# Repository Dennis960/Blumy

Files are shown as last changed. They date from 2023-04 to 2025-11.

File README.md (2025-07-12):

# Blumy

- A smart soil moisture sensor

## Project Structure

- [.devcontainer](.devcontainer): Contains the configurations for the devcontainers
- [.github](.github): Contains the configuration for GitHub Actions
- [Board](Board): Contains the KiCad project for the board
- [Panel](Panel): Contains the KiCad project for the board panel. Generation of the panel is done with `KiKit`
- [Firmware](Firmware): Contains the firmware for the esp(32) sensor (uses esp-idf)
- [Pages](Pages): Contains the website for the project's showcase
- [Server](Server): Contains the website for displaying sensor data

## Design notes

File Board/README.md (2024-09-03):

# This project uses KiCad 7

## Plugins:

- [Fabrication ToolKit](https://github.com/bennymeg/JLC-Plugin-for-KiCad)

## Other software

- [JLC2KiCadLib Downloader](https://github.com/TousstNicolas/JLC2KiCad_lib)
- inside Board run `JLC2KiCadLib C94599 C1525 C1525 C1527 C16780 C15195 C15525 C2297 C81598 C84256 C26082 C25905 C11702 C25744 C4109 C318884 C318884 C2827328 C146233 C6186 C778186 C5736265 C10418 C2997435 -dir lib -model_dir packages3d -footprint_lib CustomFootprints.pretty -symbol_lib_dir symbol -symbol_lib Custom_Parts`

## PCB Manufacturer

- [JLCPCB](https://jlcpcb.com/)

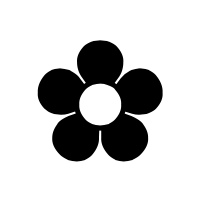
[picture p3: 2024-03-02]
Board/imgs/Flower.png

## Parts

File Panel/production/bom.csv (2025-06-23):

Designator | Footprint | Quantity | Value | LCSC Part #
BZ1_2, BZ1 | BUZ-SMD_4P-L8.5-W8.5-P8.50-BR | 2 | Buzzer | C94599
C1_2, C1, C10_2, C10, C12_2, C12, C6_2, C6, C7_2, C7, C9_2, C9 | 0402 | 12 | 10uF | C15525
C11_2, C11, C5_2, C5 | 0402 | 4 | 100nF-Ceramic | C1525
C2_2, C2 | 0402 | 2 | 10pF | C32949
C3_2, C3, C8_2, C8 | 0402 | 4 | 10nF | C15195
D1_2, D1 | LED0805-R-RD | 2 | GREEN | C2297
D2_2, D2 | SOD-123F_L2.7-W1.6-LS3.8-RD | 2 | Switching-Diode | C81598
D3_2, D3 | LED0805-R-RD | 2 | RED | C84256
L1_2, L1 | L0806 | 2 | 1.5uH | C668311
R1_2, R1 | 0402 | 2 | 287k | C321426
R10_2, R10, R11_2, R11, R12_2, R12, R2_2, R2, R4_2, R4 | 0402 | 10 | 5k1 | C25905
R13_2, R13, R14_2, R14 | 0402 | 4 | 120 | C25079
R15_2, R15 | 0402 | 2 | 51.1k | C284602
R3_2, R3 | 0402 | 2 | 100k | C25741
R5_2, R5, R8_2, R8, R9_2, R9 | 0402 | 6 | 10k | C25744
R6_2, R6 | 0402 | 2 | 2k | C4109
REF1_2, REF1 | DSBGA-8_L1.8-W1.1-R2-C4-P0.40-BR | 2 | TPS63036YFGR | C283955
U1_2, U1 | USB-C-SMD_G-SWITCH_GT-USB-7010EN | 2 | USB-C | C2997435
U13_2, U13 | WIFIM-SMD_61P-L16.6-W13.2-P0.80-ESP32-C6-MINI-1-N4 | 2 | ESP32-C6-MINI-1-N4 | C5736265
U3_2, U3 | SENSOR-SMD-6_AHT20 | 2 | AHT20 | C2757850
U4_2, U4, U7_2, U7 | SW-SMD_L3.9-W3.0-P4.45 | 4 | Tactile-Switch | C720477
U6_2, U6 | SENSORS-SMD_ALS-PT19 | 2 | Light sensor | C146233
U8_2, U8 | SW-SMD_MK-12C02-G025 | 2 | Slide-Switch | C778186

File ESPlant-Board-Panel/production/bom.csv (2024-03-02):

Designator | Footprint | Quantity | Value | LCSC Part #
BZ1_2, BZ1 | BUZ-SMD_4P-L8.5-W8.5-P8.50-BR | 2 | Buzzer | C94599
C1_2, C1 | 0402 | 2 | 2.2uF-Ceramic | C23630
C10_2, C10 | CAP-SMD_L3.2-W1.6-RD-C7171 | 2 | 10uF-Tantalum | C7171
C11_2, C11, C5_2, C5, C6_2, C6 | 0402 | 6 | 100nF-Ceramic | C1525
C2_2, C2 | CASE-B_3528 | 2 | 100uF-Tantalum | C16133
C3_2, C3, C8_2, C8 | 0402 | 4 | 10nF | C15195
C7_2, C7, C9_2, C9 | 0402 | 4 | 10uF | C15525
D1_2, D1 | LED0805-R-RD | 2 | GREEN | C2297
D2_2, D2 | SOD-123F_L2.7-W1.6-LS3.8-RD | 2 | Switching-Diode | C81598
D3_2, D3 | LED0805-R-RD | 2 | RED | C84256
L1_2, L1 | IND-SMD_L3.5-W3.0 | 2 | 6.8uH | C492260
R1_2, R1 | 0402 | 2 | 100k | C25741
R10_2, R10, R11_2, R11, R12_2, R12, R2_2, R2, R4_2, R4 | 0402 | 10 | 5k1 | C25905
R13_2, R13, R14_2, R14 | 0402 | 4 | 120 | C25079
R15_2, R15 | 0402 | 2 | 1M | C26083
R16_2, R16 | 0402 | 2 | 200k | C25764
R17_2, R17 | 0402 | 2 | 20k | C25765
R3_2, R3 | 0402 | 2 | 47k | C25792
R5_2, R5, R7_2, R7, R8_2, R8, R9_2, R9 | 0402 | 8 | 10k | C25744
R6_2, R6 | 0402 | 2 | 2k | C4109
U1_2, U1 | USB-C-SMD_G-SWITCH_GT-USB-7010EN | 2 | USB-C | C2997435
U13_2, U13 | WIFIM-SMD_61P-L16.6-W13.2-P0.80-ESP32-C6-MINI-1-N4 | 2 | ESP32-C6-MINI-1-N4 | C5736265
U3_2, U3 | SENSOR-SMD-6_AHT20 | 2 | AHT20 | C2757850
U4_2, U4, U7_2, U7 | SW-SMD_L3.9-W3.0-P4.45 | 4 | Tactile-Switch | C720477
U5_2, U5 | VSON-10_L3.0-W3.0-P0.50-BL-EP_TPS62410DRCR | 2 | 3.3V-Regulator | C71369
U6_2, U6 | SENSORS-SMD_ALS-PT19 | 2 | Light sensor | C146233
U8_2, U8 | SW-SMD_MK-12C02-G025 | 2 | Slide-Switch | C778186

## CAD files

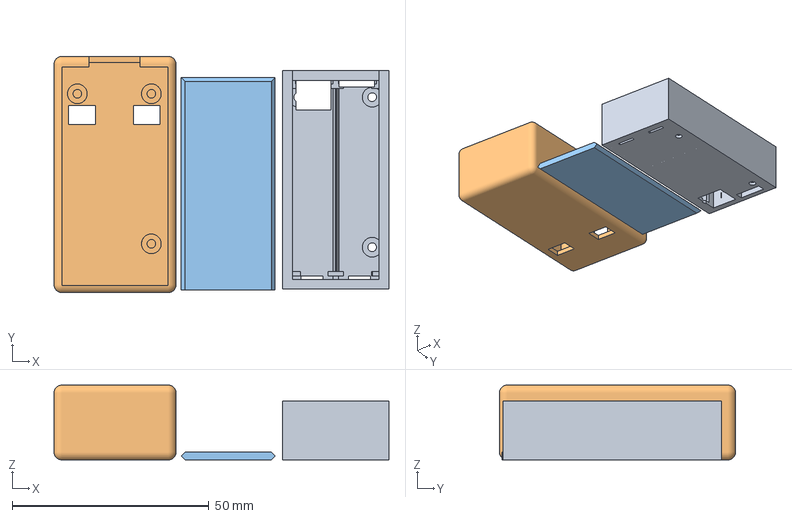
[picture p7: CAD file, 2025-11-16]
Blumy.3mf
85.1 x 60.0 x 19.0 mm
battery_holder
case
sliding_door.stl

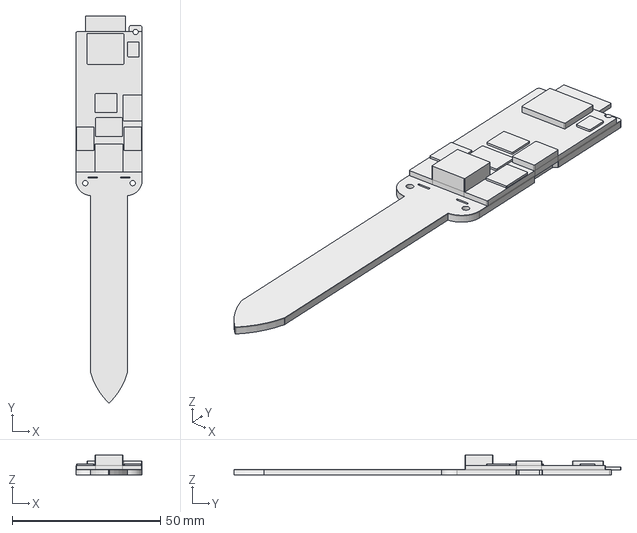
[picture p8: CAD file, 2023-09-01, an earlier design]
ESPlant-Case/v2/ESPlant-Case-v2.FCStd
22.4 x 130.6 x 6.60 mm

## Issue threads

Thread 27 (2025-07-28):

Add Server tests for the selector workflow

Dennis960, 2025-07-28:
For better quality assurance, tests should be added to the Server part of the software in the Server folder.

Currently, some e2e tests are implemented for testing authentication and the highly critical sensor api data endpoint.

In the next step, unit tests / integration tests and e2e tests should be added for the workflow of creating and assigning a sensor through the /selector page.

When a blumy sensor is configured, it opens an access point through which wifi credentials and other settings can be set. See Firmware/frontend for more information. Then, the user can enter automatic setup where the user is redirected to the Server /selector page and can either create a new sensor or use an existing sensor. The user should then be forwarded to the setup page at 192.168.4.1 with the new sensor's url and access token. This workflow should be tested thoroughly.
- Test that the redirect url is correctly used after selecting a sensor in the selector page
- Test that a new sensor can be created and is selected after creation
- Test that an existing sensor can be used and the correct url and token are passed on redirect
- Tests for changing sensor settings such as name
Note that because the redirect will happen to a local url (192.168.4.1) the actual server at that location has to be imitated to prevent errors or a different redirect url has to be chosen in order to prevent errors.

The unittests using vitest need to be added to the github workflows

Closed 2025-07-28.

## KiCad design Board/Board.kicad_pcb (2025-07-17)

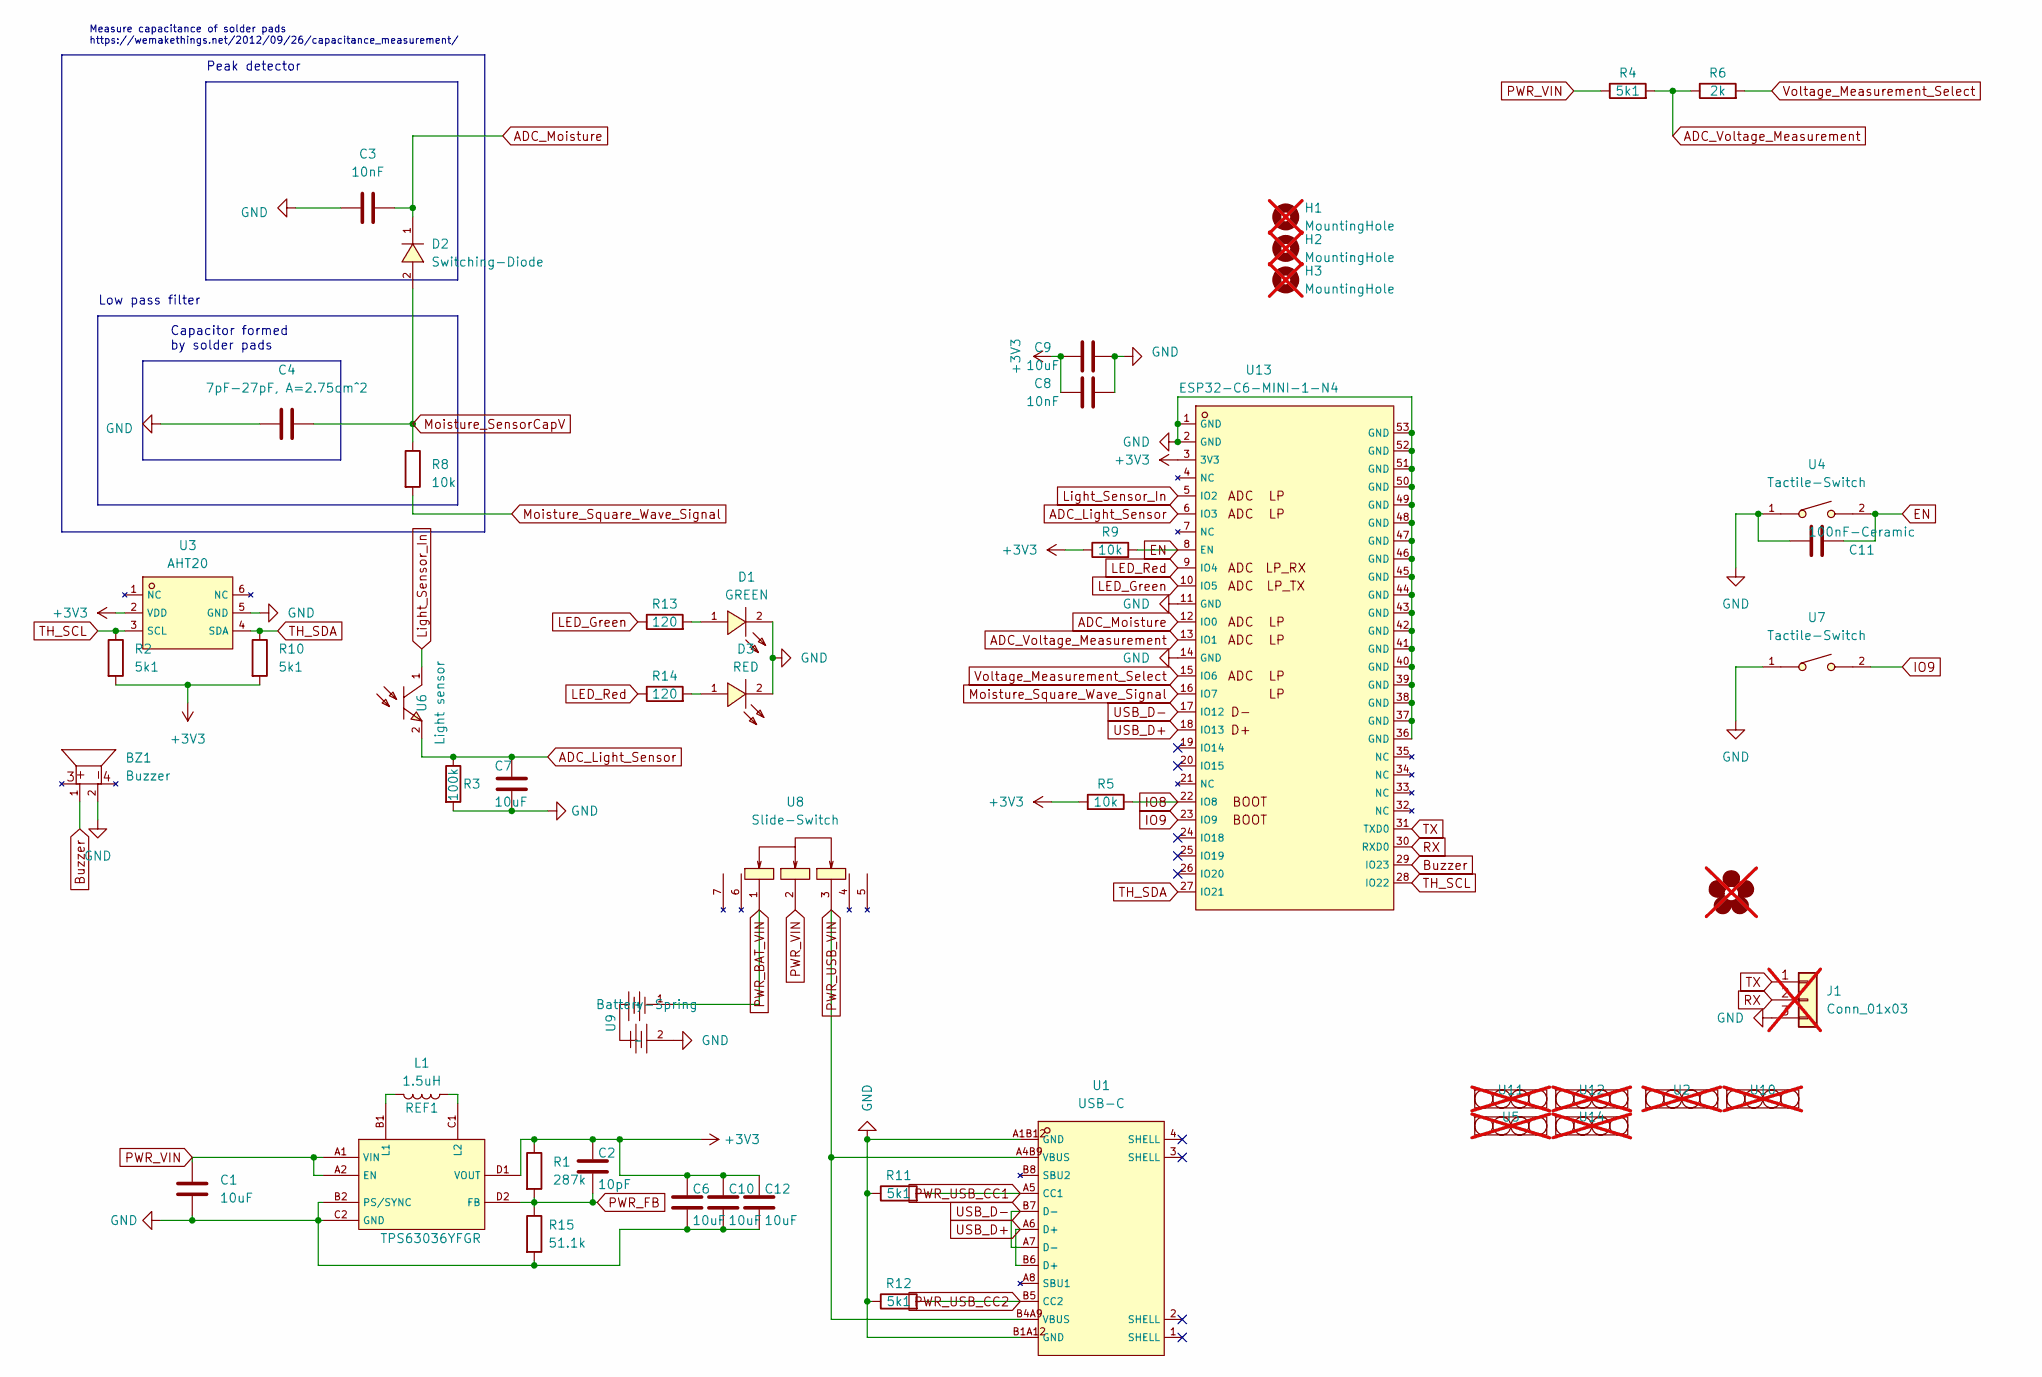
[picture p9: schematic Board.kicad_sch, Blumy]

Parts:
BZ1: Buzzer; BUZ-SMD_4P-L8.5-W8.5-P8.50-BR; MPN C94599; LCSC C94599
C1, C6, C7, C9, C10, C12: 10uF; C_0402_1005Metric; MPN C15525; LCSC C15525
C2: 10pF; C_0402_1005Metric; MPN C32949; LCSC C32949
C3, C8: 10nF; C_0402_1005Metric; MPN C15195; LCSC C15195
C4: 7pF-27pF, A=2.75cm^2; Sensor-Tip; MPN /
C11: 100nF-Ceramic; C_0402_1005Metric; MPN C1525; LCSC C1525
D1: GREEN; LED0805-R-RD; MPN C2297; LCSC C2297
D2: Switching-Diode; SOD-123F_L2.7-W1.6-LS3.8-RD; MPN C81598; LCSC C81598
D3: RED; LED0805-R-RD; MPN C84256; LCSC C84256
Flower1: Flower; MPN /; not fitted
H1, H2, H3: MountingHole; MountingHole_3.2mm_M3; MPN /; not fitted
J1: Conn_01x03; PinHeader_1x03_P2.54mm_Vertical_SMD; MPN /; not fitted
L1: 1.5uH; L0806; MPN C668311; LCSC C668311
R1: 287k; R_0402_1005Metric; MPN C321426; LCSC C321426
R2, R4, R10, R11, R12: 5k1; R_0402_1005Metric; MPN C25905; LCSC C25905
R3: 100k; R_0402_1005Metric; MPN C25741; LCSC C25741
R5, R8, R9: 10k; R_0402_1005Metric; MPN C25744; LCSC C25744
R6: 2k; R_0402_1005Metric; MPN C4109; LCSC C4109
R13, R14: 120; R_0402_1005Metric; MPN C25079; LCSC C25079
R15: 51.1k; R_0402_1005Metric; MPN C284602; LCSC C284602
REF1: TPS63036YFGR; DSBGA-8_L1.8-W1.1-R2-C4-P0.40-BR; MPN C283955; LCSC C283955
U1: USB-C; USB-C-SMD_G-SWITCH_GT-USB-7010EN; MPN C2997435; LCSC C2997435
U2, U5, U10, U11, U12, U14: MouseBites5mm; MPN /; not fitted
U3: AHT20; SENSOR-SMD-6_AHT20; MPN C2757850; LCSC C2757850
U4, U7: Tactile-Switch; SW-SMD_L3.9-W3.0-P4.45; MPN C720477; LCSC C720477
U6: Light sensor; SENSORS-SMD_ALS-PT19; MPN C146233; LCSC C146233
U8: Slide-Switch; SW-SMD_MK-12C02-G025; MPN C778186; LCSC C778186
U9: Battery-Spring; AAA Battery-spring; MPN /
U13: ESP32-C6-MINI-1-N4; WIFIM-SMD_61P-L16.6-W13.2-P0.80-ESP32-C6-MINI-1-N4; MPN C5736265; LCSC C5736265

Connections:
+3V3: C2.1, C6.1, C8.1, C9.1, C10.1, C12.1, R1.1, R2.2, R5.2, R9.1, R10.2, REF1.D1 (VOUT), U3.2 (VDD), U13.3 (3V3)
ADC_Light_Sensor: C7.1, R3.1, U6.2 (E), U13.6 (IO3)
ADC_Moisture: C3.2, D2.1 (K), U13.12 (IO0)
ADC_Voltage_Measurement: R4.2, R6.1, U13.13 (IO1)
Buzzer: BZ1.1 (+), U13.29 (IO23)
EN: C11.1, R9.2, U4.2, U13.8 (EN)
GND: BZ1.2, C1.2, C3.1, C4.2, C6.2, C7.2, C8.2, C9.2, C10.2, C11.2, C12.2, D1.2 (K), D3.2 (-), J1.3, R3.2, R11.1, R12.1, R15.2, REF1.B2 (PS/SYNC), REF1.C2 (GND), U1.A1B12 (GND), U1.B1A12 (GND), U3.5 (GND), U4.1, U7.1, U9.2 (-), U13.1 (GND), U13.2 (GND), U13.11 (GND), U13.14 (GND), U13.36 (GND), U13.37 (GND), U13.38 (GND), U13.39 (GND), U13.40 (GND), U13.41 (GND), U13.42 (GND), U13.43 (GND), U13.44 (GND), U13.45 (GND), U13.46 (GND), U13.47 (GND), U13.48 (GND), U13.49 (GND), U13.50 (GND), U13.51 (GND), U13.52 (GND), U13.53 (GND)
IO8: R5.1, U13.22 (IO8)
IO9: U7.2, U13.23 (IO9)
LED_Green: R13.1, U13.10 (IO5)
LED_Red: R14.1, U13.9 (IO4)
Light_Sensor_In: U6.1 (C), U13.5 (IO2)
Moisture_SensorCapV: C4.1, D2.2 (A), R8.1
Moisture_Square_Wave_Signal: R8.2, U13.16 (IO7)
unnamed: D1.1 (A), R13.2
unnamed: D3.1 (+), R14.2
unnamed: L1.2, REF1.B1 (L1)
unnamed: L1.1, REF1.C1 (L2)
PWR_BAT_VIN: U8.1, U9.1 (+)
PWR_FB: C2.2, R1.2, R15.1, REF1.D2 (FB)
PWR_USB_CC1: R11.2, U1.A5 (CC1)
PWR_USB_CC2: R12.2, U1.B5 (CC2)
PWR_USB_VIN: U1.A4B9 (VBUS), U1.B4A9 (VBUS), U8.3
PWR_VIN: C1.1, R4.1, REF1.A1 (VIN), REF1.A2 (EN), U8.2
RX: J1.2, U13.30 (RXD0)
TH_SCL: R2.1, U3.3 (SCL), U13.28 (IO22)
TH_SDA: R10.1, U3.4 (SDA), U13.27 (IO21)
TX: J1.1, U13.31 (TXD0)
USB_D+: U1.A6 (D+), U1.B6 (D+), U13.18 (IO13)
USB_D-: U1.A7 (D-), U1.B7 (D-), U13.17 (IO12)
Voltage_Measurement_Select: R6.2, U13.15 (IO6)

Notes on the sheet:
Capacitor formed by solder pads
Measure capacitance of solder pads https://wemakethings.net/2012/09/26/capacitance_measurement/
Peak detector
Low pass filter

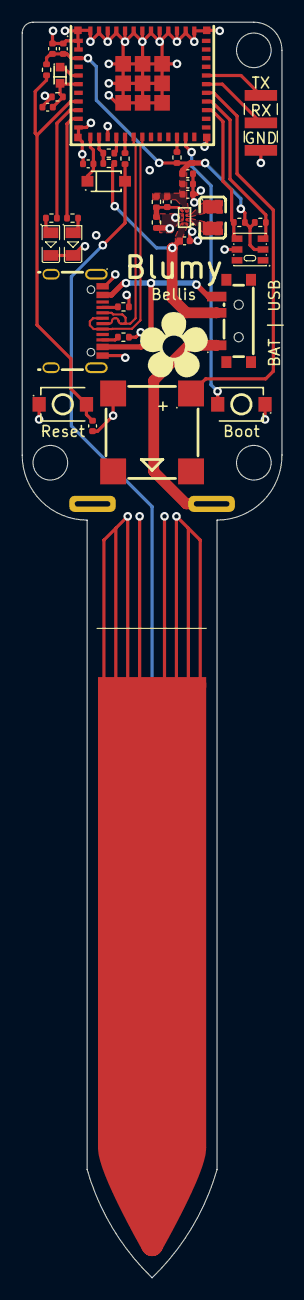
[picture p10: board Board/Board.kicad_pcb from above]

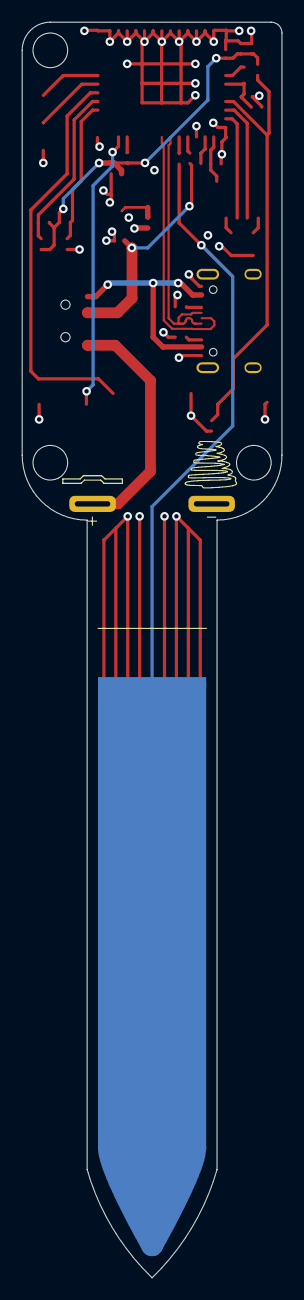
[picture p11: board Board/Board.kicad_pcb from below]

Board: 4 copper layers, 24.0 x 116.0 mm, 50 parts (2 on the bottom side), 31 nets.

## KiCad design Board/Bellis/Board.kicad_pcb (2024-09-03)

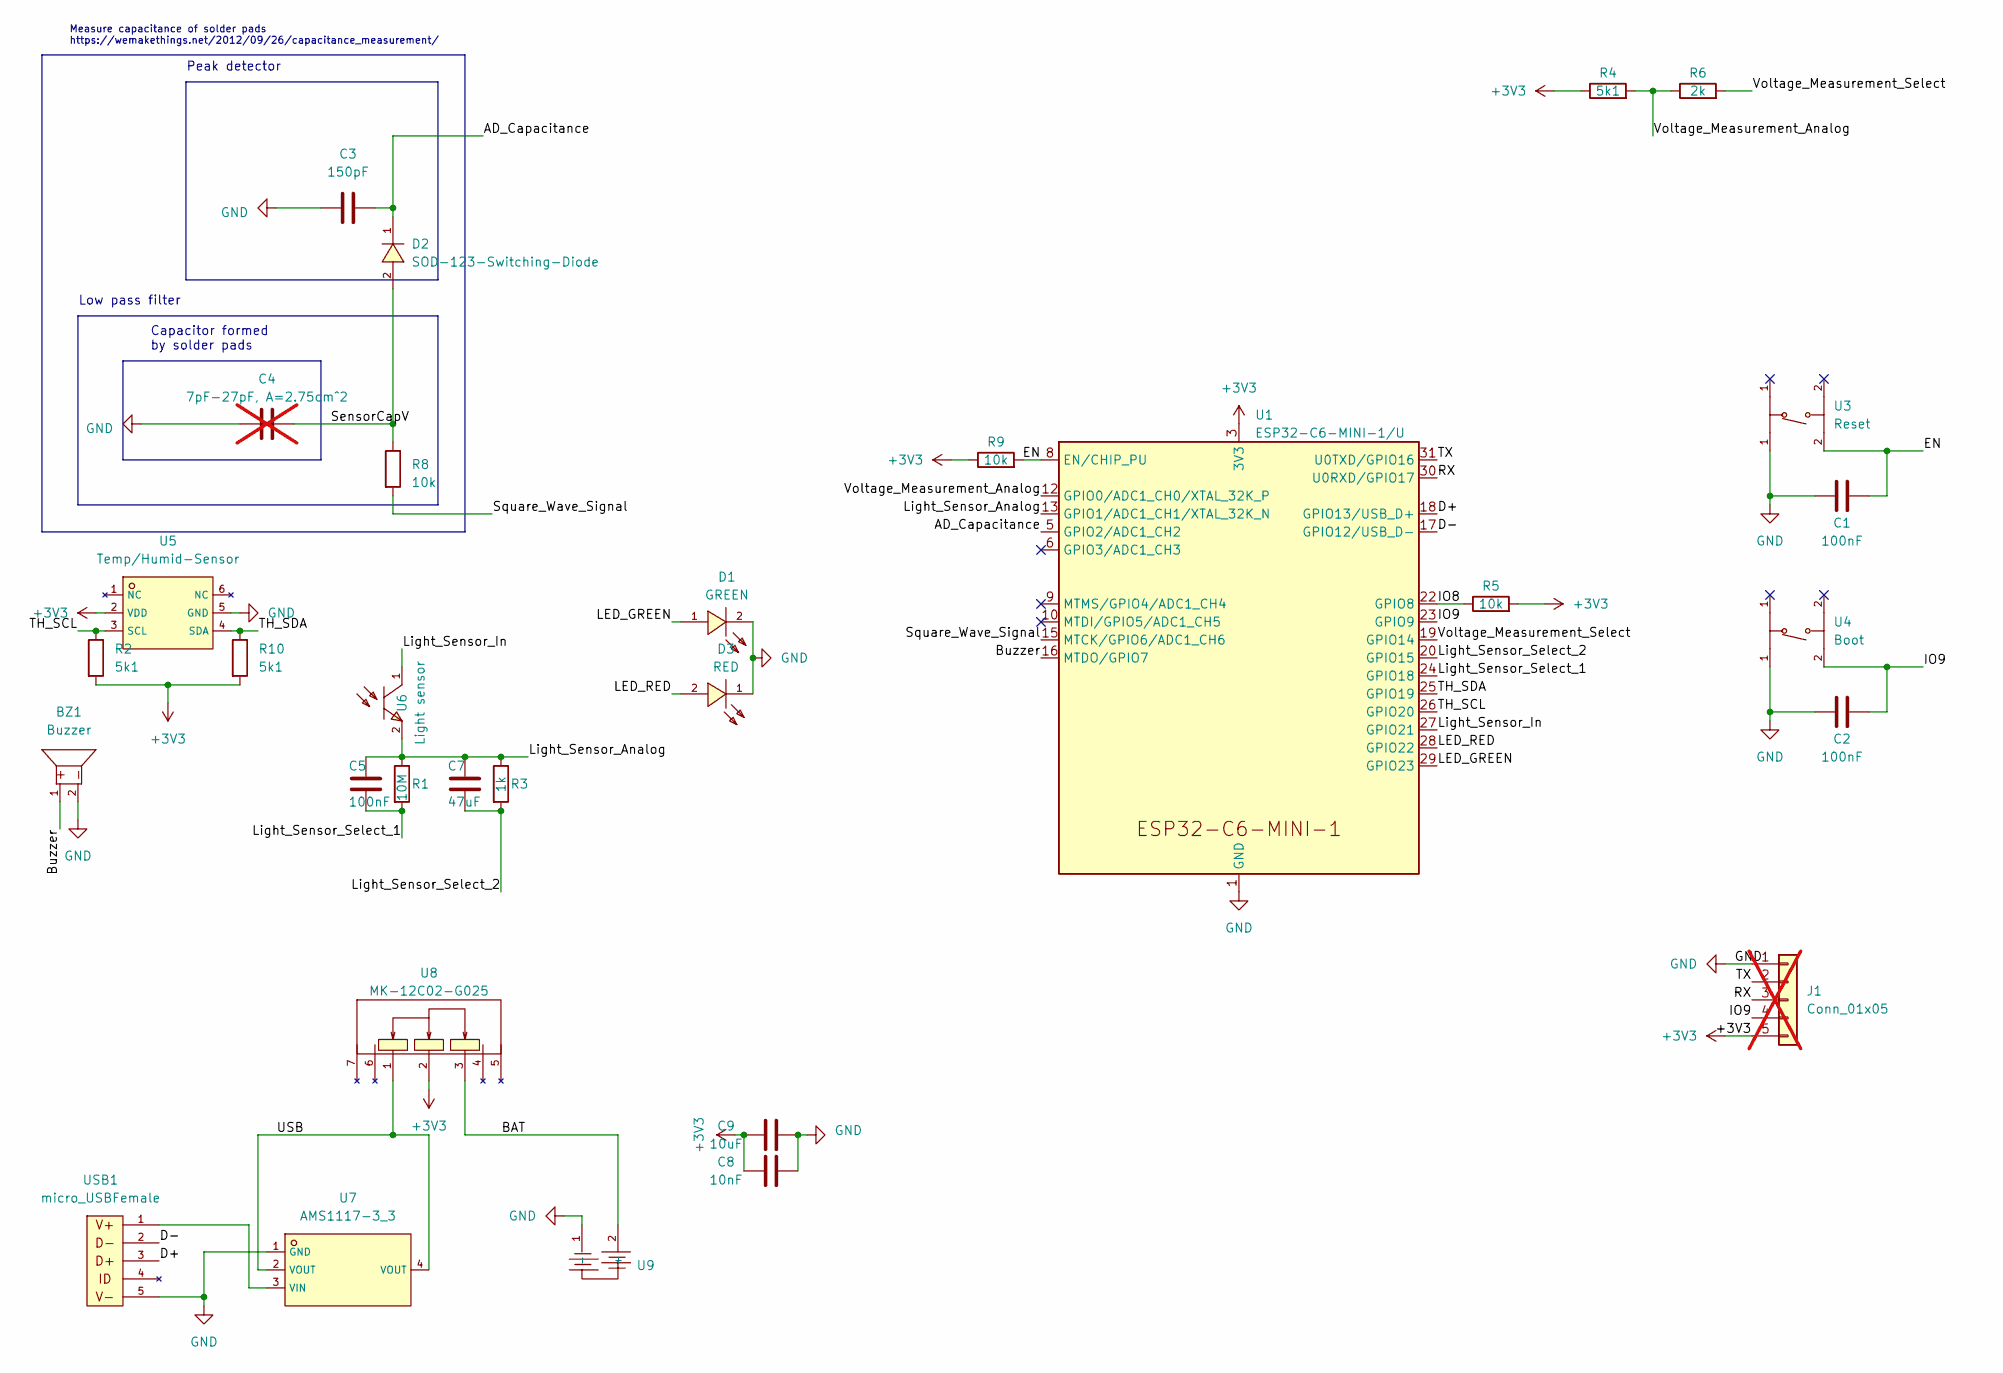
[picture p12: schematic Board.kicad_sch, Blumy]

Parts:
BZ1: Buzzer; BUZ-SMD_4P-L8.5-W8.5-P8.50-BR; MPN C94599; LCSC C94599
C1, C2, C5: 100nF; C_0402_1005Metric; MPN C1525; LCSC C1525
C3: 150pF; C_0402_1005Metric; MPN C1527; LCSC C1527
C4: 7pF-27pF, A=2.75cm^2; MPN /; LCSC /; not fitted
C7: 47uF; C_0805_2012Metric; MPN C16780; LCSC C16780
C8: 10nF; C_0402_1005Metric; MPN C15195; LCSC C15195
C9: 10uF; C_0402_1005Metric; MPN C15525; LCSC C15525
D1: GREEN; LED0805-GREEN-RD; MPN C2297; LCSC C2297
D2: SOD-123-Switching-Diode; SOD-123F_L2.7-W1.6-LS3.8-RD; MPN C81598; LCSC C81598
D3: RED; LED0805-RD_RED; MPN C84256; LCSC C84256
J1: Conn_01x05; PinHeader_1x05_P2.54mm_Vertical; MPN /; LCSC /; not fitted
R1: 10M; R_0402_1005Metric; MPN C26082; LCSC C26082
R2, R4, R10: 5k1; R_0402_1005Metric; MPN C25905; LCSC C25905
R3: 1k; R_0402_1005Metric; MPN C11702; LCSC C11702
R5, R8, R9: 10k; R_0402_1005Metric; MPN C25744; LCSC C25744
R6: 2k; R_0402_1005Metric; MPN C4109; LCSC C4109
U1: ESP32-C6-MINI-1/U; ESP32-C6-MINI-1; MPN C5736265; LCSC C5736265
U3: Reset; SW_Push_1P1T_XKB_TS-1187A; MPN C318884; LCSC C318884
U4: Boot; SW_Push_1P1T_XKB_TS-1187A; MPN C318884; LCSC C318884
U5: Temp/Humid-Sensor; SENSOR-SMD_L3.0-W3.0-P1.00-BR; MPN C2827328; LCSC C2827328
U6: Light sensor; SENSORS-SMD_ALS-PT19; MPN C146233; LCSC C146233
U7: AMS1117-3_3; SOT-223-3_L6.5-W3.4-P2.30-LS7.0-BR; MPN C6186; LCSC C6186
U8: MK-12C02-G025; SW-SMD_MK-12C02-G025; MPN C778186; LCSC C778186
U9: AAA Battery-spring; MPN /; LCSC /
USB1: micro_USBFemale; MICRO-USB-SMD_5P-P0.65-H-F_C10418; MPN C10418; LCSC C10418

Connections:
+3V3: C8.1, C9.1, J1.5, R2.2, R4.1, R5.2, R9.1, R10.2, U1.3 (3V3), U5.2 (VDD), U8.2
/AD_Capacitance: C3.2, D2.1 (K), U1.5 (GPIO2/ADC1_CH2)
/BAT: U8.3, U9.2 (+)
/Buzzer: BZ1.1 (+), U1.16 (MTDO/GPIO7)
/D+: U1.18 (GPIO13/USB_D+), USB1.3 (D+)
/D-: U1.17 (GPIO12/USB_D-), USB1.2 (D-)
/EN: C1.2, R9.2, U1.8 (EN/CHIP_PU), U3.2 (C)
/IO8: R5.1, U1.22 (GPIO8)
/IO9: C2.2, J1.4, U1.23 (GPIO9), U4.2 (C)
/LED_GREEN: D1.1 (A), U1.29 (GPIO23)
/LED_RED: D3.2 (+), U1.28 (GPIO22)
/Light_Sensor_Analog: C5.1, C7.1, R1.1, R3.1, U1.13 (GPIO1/ADC1_CH1/XTAL_32K_N), U6.2 (E)
/Light_Sensor_In: U1.27 (GPIO21), U6.1 (C)
/Light_Sensor_Select_1: C5.2, R1.2, U1.24 (GPIO18)
/Light_Sensor_Select_2: C7.2, R3.2, U1.20 (GPIO15)
/RX: J1.3, U1.30 (U0RXD/GPIO17)
/SensorCapV: C4.2, D2.2 (A), R8.1
/Square_Wave_Signal: R8.2, U1.15 (MTCK/GPIO6/ADC1_CH6)
/TH_SCL: R2.1, U1.26 (GPIO20), U5.3 (SCL)
/TH_SDA: R10.1, U1.25 (GPIO19), U5.4 (SDA)
/TX: J1.2, U1.31 (U0TXD/GPIO16)
/USB: U7.2 (VOUT), U7.4 (VOUT), U8.1
/Voltage_Measurement_Analog: R4.2, R6.1, U1.12 (GPIO0/ADC1_CH0/XTAL_32K_P)
/Voltage_Measurement_Select: R6.2, U1.19 (GPIO14)
GND: BZ1.2, C1.1, C2.1, C3.1, C4.1, C8.2, C9.2, D1.2 (K), D3.1 (-), J1.1, U1.1 (GND), U1.2 (GND), U1.11 (GND), U1.14 (GND), U1.36 (GND), U1.37 (GND), U1.38 (GND), U1.39 (GND), U1.40 (GND), U1.41 (GND), U1.42 (GND), U1.43 (GND), U1.44 (GND), U1.45 (GND), U1.46 (GND), U1.47 (GND), U1.48 (GND), U1.49 (GND), U1.50 (GND), U1.51 (GND), U1.52 (GND), U1.53 (GND), U3.1 (A), U4.1 (A), U5.5 (GND), U7.1 (GND), U9.1 (-), USB1.5 (V-)
unnamed: U7.3 (VIN), USB1.1 (V+)

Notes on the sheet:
Capacitor formed by solder pads
Measure capacitance of solder pads https://wemakethings.net/2012/09/26/capacitance_measurement/
Peak detector
Low pass filter

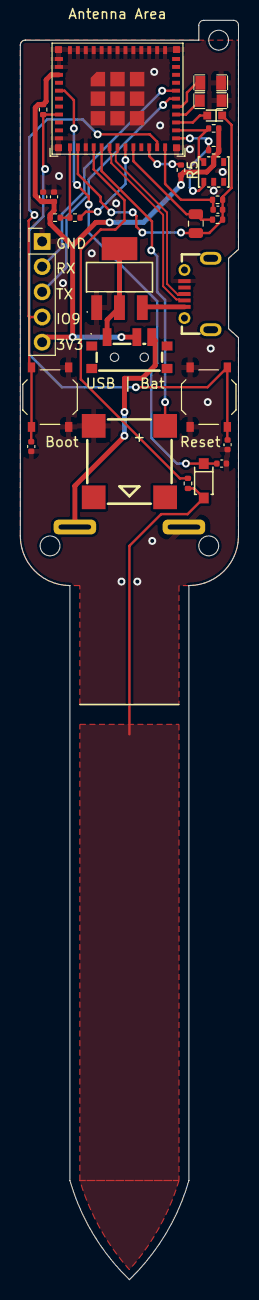
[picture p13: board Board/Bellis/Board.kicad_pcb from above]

Board: 2 copper layers, 22.0 x 127.0 mm, 30 parts (1 on the bottom side), 26 nets.

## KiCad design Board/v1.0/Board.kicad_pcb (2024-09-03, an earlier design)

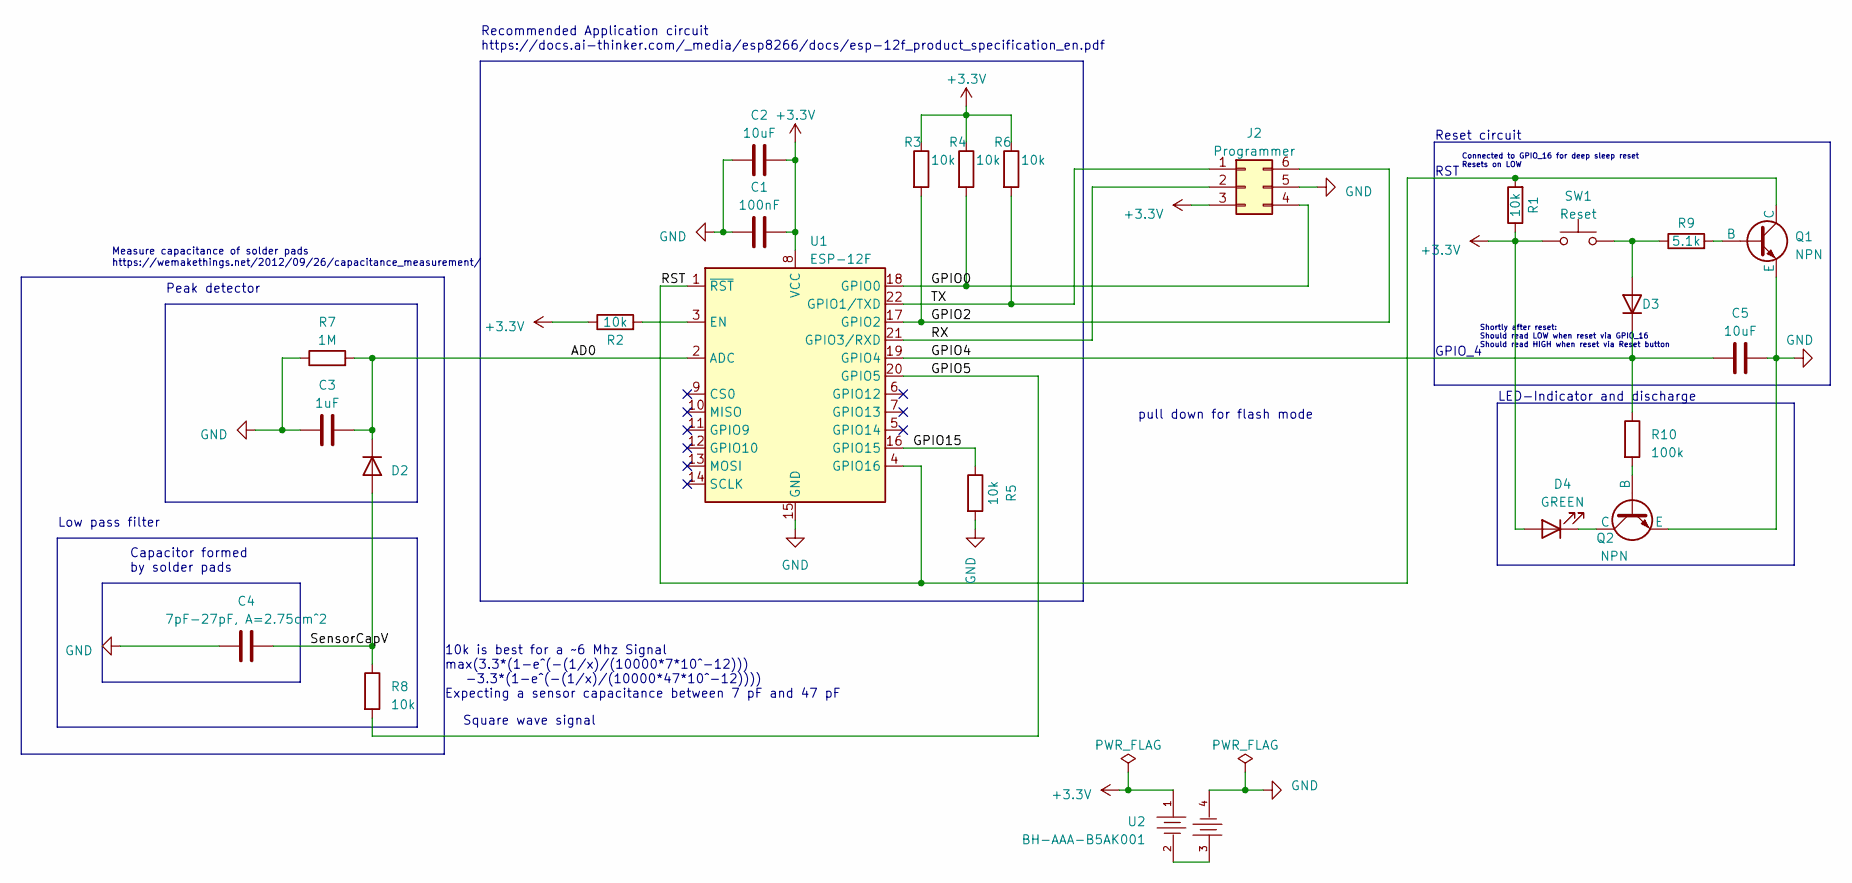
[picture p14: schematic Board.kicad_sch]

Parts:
C1: 100nF; C_0402_1005Metric; MPN C1525; LCSC C1525
C2, C5: 10uF; C_0402_1005Metric; MPN C15525; LCSC C15525
C3: 1uF; C_0402_1005Metric; MPN C52923; LCSC C52923
C4: 7pF-27pF, A=2.75cm^2
D2, D3: D_SOD-123F; MPN C81598; LCSC C81598
D4: GREEN; LED_0805_2012Metric; MPN C2297; LCSC C2297
J2: Programmer; PinHeader_2x03_P2.54mm_Vertical
Q1, Q2: NPN; SOT-23; MPN C2146; LCSC C2146
R1, R2, R3, R4, R5, R6, R8: 10k; R_0402_1005Metric; MPN C25744; LCSC C25744
R7: 1M; R_0402_1005Metric; MPN C26083; LCSC C26083
R9: 5.1k; R_0402_1005Metric; MPN C25905; LCSC C25905
R10: 100k; R_0402_1005Metric; MPN C25741; LCSC C25741
SW1: Reset; SW_Push_1P1T_XKB_TS-1187A; MPN C318884; LCSC C318884
U1: ESP-12F; ESP-12E; MPN C82891; LCSC C82891
U2: BH-AAA-B5AK001; BAT-SMD_BH-AAA-B5AA001; MPN C964881; LCSC C964881

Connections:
+3.3V: C1.2, C2.2, D4.2 (A), J2.3, R1.1, R2.1, R3.1, R4.1, R6.1, SW1.1, U1.8 (VCC), U2.1 (+)
/AD0: C3.2, D2.1 (K), R7.2, U1.2 (ADC)
/GPIO0: J2.4, R4.2, U1.18 (GPIO0)
/GPIO2: J2.6, R3.2, U1.17 (GPIO2)
/GPIO4: C5.1, D3.1 (K), R10.1, U1.19 (GPIO4)
/GPIO5: R8.2, U1.20 (GPIO5)
/GPIO15: R5.1, U1.16 (GPIO15)
/RST: Q1.1 (C), R1.2, U1.1 (~RST), U1.4 (GPIO16)
/RX: J2.2, U1.21 (GPIO3/RXD)
/SensorCapV: C4.2, D2.2 (A), R8.1
/TX: J2.1, R6.2, U1.22 (GPIO1/TXD)
GND: C1.1, C2.1, C3.1, C4.1, C5.2, J2.5, Q1.3 (E), Q2.3 (E), R5.2, R7.1, U1.15 (GND), U2.4 (-)
unnamed: D3.2 (A), R9.1, SW1.2
unnamed: D4.1 (K), Q2.1 (C)
unnamed: Q1.2 (B), R9.2
unnamed: Q2.2 (B), R10.2
unnamed: R2.2, U1.3 (EN)
unnamed: U2.2 (-), U2.3 (+)

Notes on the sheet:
Capacitor formed by solder pads
Square wave signal
10k is best for a ~6 Mhz Signal max(3.3*(1-e^(-(1/x)/(10000*7*10^-12))) -3.3*(1-e^(-(1/x)/(10000*47*10^-12)))) Expecting a sensor capacitance between 7 pF and 47 pF
Connected to GPIO_16 for deep sleep reset Resets on LOW
Shortly after reset: Should read LOW when reset via GPIO_16 Should read HIGH when reset via Reset button
Recommended Application circuit https://docs.ai-thinker.com/_media/esp8266/docs/esp-12f_product_specification_en.pdf
GPIO_4
Measure capacitance of solder pads https://wemakethings.net/2012/09/26/capacitance_measurement/
Peak detector
RST
pull down for flash mode
Low pass filter
LED-Indicator and discharge
Reset circuit

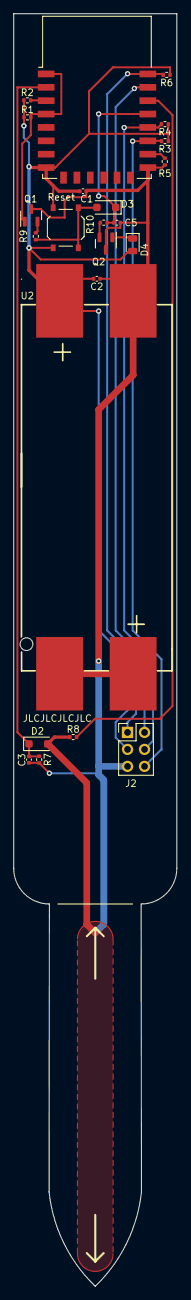
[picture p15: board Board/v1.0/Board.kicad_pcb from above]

Board: 2 copper layers, 24.4 x 190.2 mm, 23 parts (0 on the bottom side), 18 nets.

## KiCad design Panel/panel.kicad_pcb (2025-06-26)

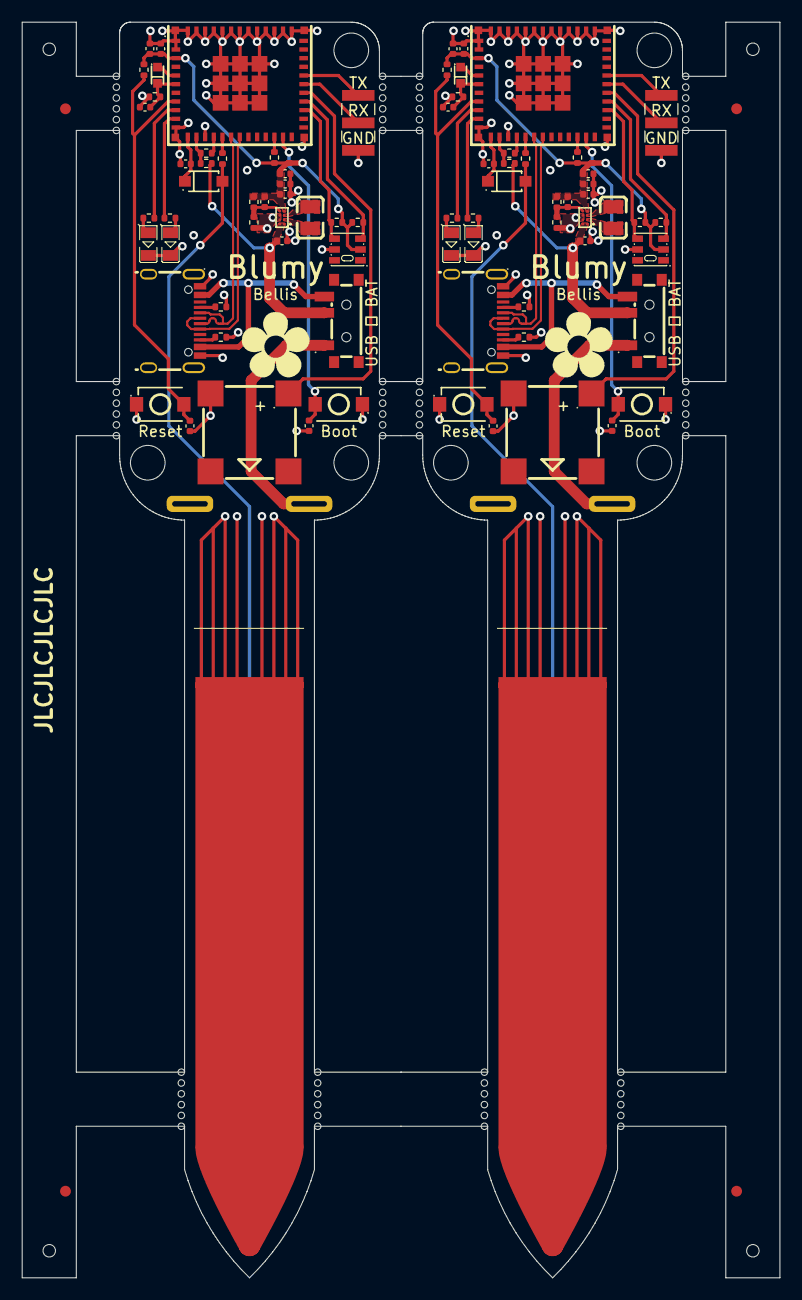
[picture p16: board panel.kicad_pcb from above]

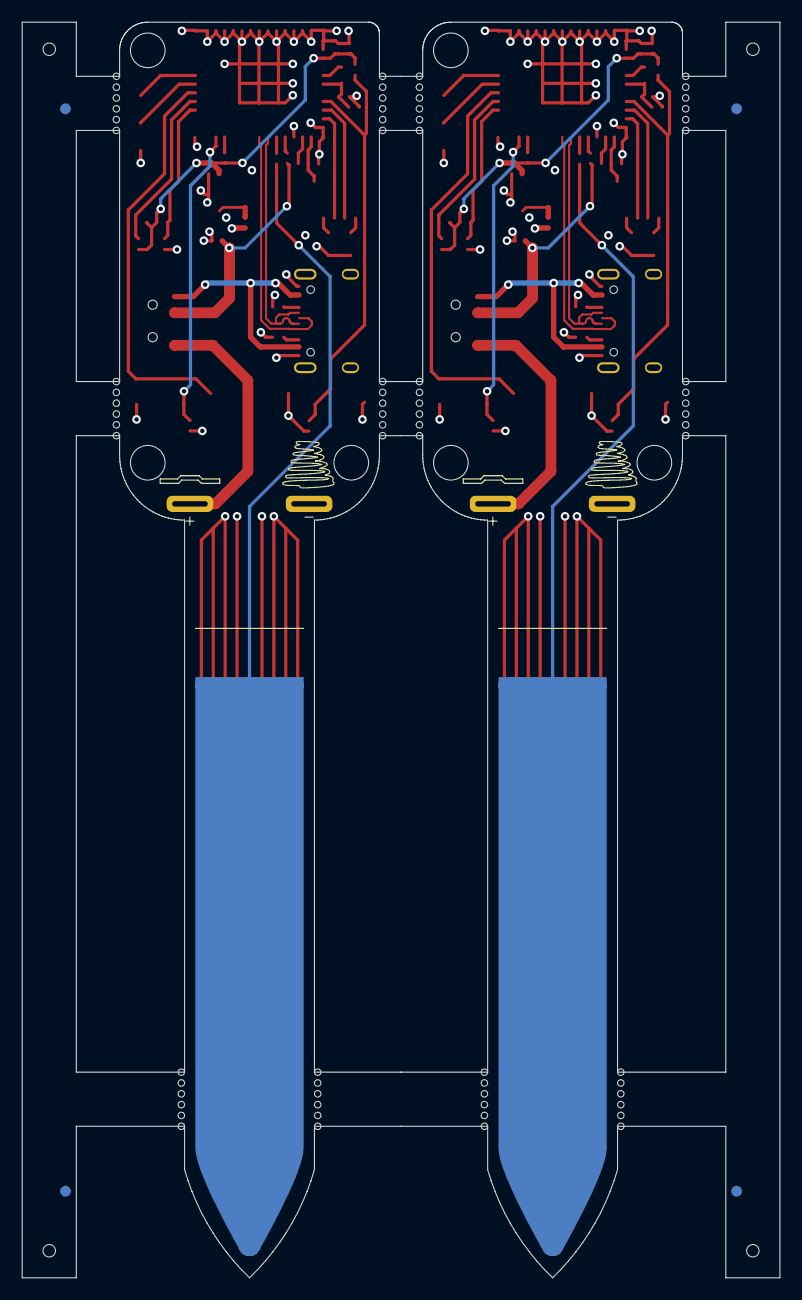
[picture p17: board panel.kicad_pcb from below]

Board: 4 copper layers, 70.0 x 116.0 mm, 174 parts (8 on the bottom side), 62 nets.

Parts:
BZ1, BZ1#2: Buzzer; BUZ-SMD_4P-L8.5-W8.5-P8.50-BR
C1, C1#2, C6, C6#2, C7, C7#2, C9, C9#2, C10, C10#2, C12, C12#2: 10uF; C_0402_1005Metric
C2, C2#2: 10pF; C_0402_1005Metric
C3, C3#2, C8, C8#2: 10nF; C_0402_1005Metric
C4, C4#2: 7pF-27pF, A=2.75cm^2; Sensor-Tip
C5, C5#2, C11, C11#2: 100nF-Ceramic; C_0402_1005Metric
D1, D1#2: GREEN; LED0805-R-RD
D2, D2#2: Switching-Diode; SOD-123F_L2.7-W1.6-LS3.8-RD
D3, D3#2: RED; LED0805-R-RD
Flower1, Flower1#2: Flower
H1, H1#2, H2, H2#2, H3, H3#2: MountingHole; MountingHole_3.2mm_M3
J1, J1#2: Conn_01x03; PinHeader_1x03_P2.54mm_Vertical_SMD
KiKit_FID_B_1, KiKit_FID_B_2, KiKit_FID_B_3, KiKit_FID_B_4: Fiducial
KiKit_FID_T_1, KiKit_FID_T_2, KiKit_FID_T_3, KiKit_FID_T_4: Fiducial
KiKit_MB_1_1, KiKit_MB_1_2, KiKit_MB_1_3, KiKit_MB_1_4, KiKit_MB_1_5, KiKit_MB_1_6, KiKit_MB_2_1, KiKit_MB_2_2, KiKit_MB_2_3, KiKit_MB_2_4, KiKit_MB_2_5, KiKit_MB_2_6, KiKit_MB_3_1, KiKit_MB_3_2, KiKit_MB_3_3, KiKit_MB_3_4, KiKit_MB_3_5, KiKit_MB_3_6, KiKit_MB_4_1, KiKit_MB_4_2, KiKit_MB_4_3, KiKit_MB_4_4, KiKit_MB_4_5, KiKit_MB_4_6, KiKit_MB_5_1, KiKit_MB_5_2, KiKit_MB_5_3, KiKit_MB_5_4, KiKit_MB_5_5, KiKit_MB_5_6, KiKit_MB_6_1, KiKit_MB_6_2, KiKit_MB_6_3, KiKit_MB_6_4, KiKit_MB_6_5, KiKit_MB_6_6, KiKit_MB_7_1, KiKit_MB_7_2, KiKit_MB_7_3, KiKit_MB_7_4, KiKit_MB_7_5, KiKit_MB_7_6, KiKit_MB_8_1, KiKit_MB_8_2, KiKit_MB_8_3, KiKit_MB_8_4, KiKit_MB_8_5, KiKit_MB_8_6, KiKit_MB_9_1, KiKit_MB_9_2, KiKit_MB_9_3, KiKit_MB_9_4, KiKit_MB_9_5, KiKit_MB_9_6, KiKit_MB_10_1, KiKit_MB_10_2, KiKit_MB_10_3, KiKit_MB_10_4, KiKit_MB_10_5, KiKit_MB_10_6, KiKit_MB_11_1, KiKit_MB_11_2, KiKit_MB_11_3, KiKit_MB_11_4, KiKit_MB_11_5, KiKit_MB_11_6, KiKit_MB_12_1, KiKit_MB_12_2, KiKit_MB_12_3, KiKit_MB_12_4, KiKit_MB_12_5, KiKit_MB_12_6: NPTH
KiKit_TO_1, KiKit_TO_2, KiKit_TO_3, KiKit_TO_4: NPTH
L1, L1#2: 1.5uH; L0806
R1, R1#2: 287k; R_0402_1005Metric
R2, R2#2, R4, R4#2, R10, R10#2, R11, R11#2, R12, R12#2: 5k1; R_0402_1005Metric
R3, R3#2: 100k; R_0402_1005Metric
R5, R5#2, R8, R8#2, R9, R9#2: 10k; R_0402_1005Metric
R6, R6#2: 2k; R_0402_1005Metric
R13, R13#2, R14, R14#2: 120; R_0402_1005Metric
R15, R15#2: 51.1k; R_0402_1005Metric
REF1, REF1#2: TPS63036YFGR; DSBGA-8_L1.8-W1.1-R2-C4-P0.40-BR
U1, U1#2: USB-C; USB-C-SMD_G-SWITCH_GT-USB-7010EN
U3, U3#2: AHT20; SENSOR-SMD-6_AHT20
U4, U4#2, U7, U7#2: Tactile-Switch; SW-SMD_L3.9-W3.0-P4.45
U6, U6#2: Light sensor; SENSORS-SMD_ALS-PT19
U8, U8#2: Slide-Switch; SW-SMD_MK-12C02-G025
U9, U9#2: Battery-Spring; AAA Battery-spring
U13, U13#2: ESP32-C6-MINI-1-N4; WIFIM-SMD_61P-L16.6-W13.2-P0.80-ESP32-C6-MINI-1-N4

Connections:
Board_0-+3V3: C2#2.1, C6#2.1, C8#2.1, C9.1, C10#2.1, C12.1, R1#2.1, R2.2, R5.2, R9#2.1, R10.2, REF1#2.D1 (VOUT), U3#2.2 (VDD), U13.3 (3V3)
Board_0-ADC_Light_Sensor: C7#2.1, R3#2.1, U6#2.2 (E), U13.6 (IO3)
Board_0-ADC_Moisture: C3.2, D2.1 (K), U13.12 (IO0)
Board_0-ADC_Voltage_Measurement: R4#2.2, R6#2.1, U13.13 (IO1)
Board_0-Buzzer: BZ1.1 (+), U13.29 (IO23)
Board_0-EN: C11#2.1, R9#2.2, U4#2.2, U13.8 (EN)
Board_0-GND: BZ1.2, C1.2, C3.1, C4.2, C5.2, C6#2.2, C7#2.2, C8#2.2, C9.2, C10#2.2, C11#2.2, C12.2, D1.2 (K), D3.2 (-), J1#2.3, R3#2.2, R11#2.1, R12.1, R15#2.2, REF1#2.B2 (PS/SYNC), REF1#2.C2 (GND), U1.A1B12 (GND), U1.B1A12 (GND), U3#2.5 (GND), U4#2.1, U7#2.1, U9.2 (-), U13.1 (GND), U13.2 (GND), U13.11 (GND), U13.14 (GND), U13.36 (GND), U13.37 (GND), U13.38 (GND), U13.39 (GND), U13.40 (GND), U13.41 (GND), U13.42 (GND), U13.43 (GND), U13.44 (GND), U13.45 (GND), U13.46 (GND), U13.47 (GND), U13.48 (GND), U13.49 (GND), U13.50 (GND), U13.51 (GND), U13.52 (GND), U13.53 (GND)
Board_0-IO8: R5.1, U13.22 (IO8)
Board_0-IO9: C5.1, U7#2.2, U13.23 (IO9)
Board_0-LED_Green: R13.1, U13.10 (IO5)
Board_0-LED_Red: R14#2.1, U13.9 (IO4)
Board_0-Light_Sensor_In: U6#2.1 (C), U13.5 (IO2)
Board_0-Moisture_SensorCapV: C4.1, D2.2 (A), R8.1
Board_0-Moisture_Square_Wave_Signal: R8.2, U13.16 (IO7)
Board_0-Net-(D1-A): D1.1 (A), R13.2
Board_0-Net-(D3-+): D3.1 (+), R14#2.2
Board_0-Net-(REF1-L1): L1.2, REF1#2.B1 (L1)
Board_0-Net-(REF1-L2): L1.1, REF1#2.C1 (L2)
Board_0-PWR_BAT_VIN: U8.1, U9.1 (+)
Board_0-PWR_FB: C2#2.2, R1#2.2, R15#2.1, REF1#2.D2 (FB)
Board_0-PWR_USB_CC1: R11#2.2, U1.A5 (CC1)
Board_0-PWR_USB_CC2: R12.2, U1.B5 (CC2)
Board_0-PWR_USB_VIN: U1.A4B9 (VBUS), U1.B4A9 (VBUS), U8.3
Board_0-PWR_VIN: C1.1, R4#2.1, REF1#2.A1 (VIN), REF1#2.A2 (EN), U8.2
Board_0-RX: J1#2.2, U13.30 (RXD0)
Board_0-TH_SCL: R2.1, U3#2.3 (SCL), U13.28 (IO22)
Board_0-TH_SDA: R10.1, U3#2.4 (SDA), U13.27 (IO21)
Board_0-TX: J1#2.1, U13.31 (TXD0)
Board_0-USB_D+: U1.A6 (D+), U1.B6 (D+), U13.18 (IO13)
Board_0-USB_D-: U1.A7 (D-), U1.B7 (D-), U13.17 (IO12)
Board_0-Voltage_Measurement_Select: R6#2.2, U13.15 (IO6)
Board_1-+3V3: C2.1, C6.1, C8.1, C9#2.1, C10.1, C12#2.1, R1.1, R2#2.2, R5#2.2, R9.1, R10#2.2, REF1.D1 (VOUT), U3.2 (VDD), U13#2.3 (3V3)
Board_1-ADC_Light_Sensor: C7.1, R3.1, U6.2 (E), U13#2.6 (IO3)
Board_1-ADC_Moisture: C3#2.2, D2#2.1 (K), U13#2.12 (IO0)
Board_1-ADC_Voltage_Measurement: R4.2, R6.1, U13#2.13 (IO1)
Board_1-Buzzer: BZ1#2.1 (+), U13#2.29 (IO23)
Board_1-EN: C11.1, R9.2, U4.2, U13#2.8 (EN)
Board_1-GND: BZ1#2.2, C1#2.2, C3#2.1, C4#2.2, C5#2.2, C6.2, C7.2, C8.2, C9#2.2, C10.2, C11.2, C12#2.2, D1#2.2 (K), D3#2.2 (-), J1.3, R3.2, R11.1, R12#2.1, R15.2, REF1.B2 (PS/SYNC), REF1.C2 (GND), U1#2.A1B12 (GND), U1#2.B1A12 (GND), U3.5 (GND), U4.1, U7.1, U9#2.2 (-), U13#2.1 (GND), U13#2.2 (GND), U13#2.11 (GND), U13#2.14 (GND), U13#2.36 (GND), U13#2.37 (GND), U13#2.38 (GND), U13#2.39 (GND), U13#2.40 (GND), U13#2.41 (GND), U13#2.42 (GND), U13#2.43 (GND), U13#2.44 (GND), U13#2.45 (GND), U13#2.46 (GND), U13#2.47 (GND), U13#2.48 (GND), U13#2.49 (GND), U13#2.50 (GND), U13#2.51 (GND), U13#2.52 (GND), U13#2.53 (GND)
Board_1-IO8: R5#2.1, U13#2.22 (IO8)
Board_1-IO9: C5#2.1, U7.2, U13#2.23 (IO9)
Board_1-LED_Green: R13#2.1, U13#2.10 (IO5)
Board_1-LED_Red: R14.1, U13#2.9 (IO4)
Board_1-Light_Sensor_In: U6.1 (C), U13#2.5 (IO2)
Board_1-Moisture_SensorCapV: C4#2.1, D2#2.2 (A), R8#2.1
Board_1-Moisture_Square_Wave_Signal: R8#2.2, U13#2.16 (IO7)
Board_1-Net-(D1-A): D1#2.1 (A), R13#2.2
Board_1-Net-(D3-+): D3#2.1 (+), R14.2
Board_1-Net-(REF1-L1): L1#2.2, REF1.B1 (L1)
Board_1-Net-(REF1-L2): L1#2.1, REF1.C1 (L2)
Board_1-PWR_BAT_VIN: U8#2.1, U9#2.1 (+)
Board_1-PWR_FB: C2.2, R1.2, R15.1, REF1.D2 (FB)
Board_1-PWR_USB_CC1: R11.2, U1#2.A5 (CC1)
Board_1-PWR_USB_CC2: R12#2.2, U1#2.B5 (CC2)
Board_1-PWR_USB_VIN: U1#2.A4B9 (VBUS), U1#2.B4A9 (VBUS), U8#2.3
Board_1-PWR_VIN: C1#2.1, R4.1, REF1.A1 (VIN), REF1.A2 (EN), U8#2.2
Board_1-RX: J1.2, U13#2.30 (RXD0)
Board_1-TH_SCL: R2#2.1, U3.3 (SCL), U13#2.28 (IO22)
Board_1-TH_SDA: R10#2.1, U3.4 (SDA), U13#2.27 (IO21)
Board_1-TX: J1.1, U13#2.31 (TXD0)
Board_1-USB_D+: U1#2.A6 (D+), U1#2.B6 (D+), U13#2.18 (IO13)
Board_1-USB_D-: U1#2.A7 (D-), U1#2.B7 (D-), U13#2.17 (IO12)
Board_1-Voltage_Measurement_Select: R6.2, U13#2.15 (IO6)

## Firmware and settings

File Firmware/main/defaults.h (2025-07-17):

#pragma once

#define DEFAULT_SENSOR_TIMEOUT_SLEEP_MS 1000 * 60 * 60 // 60 minutes
#define DEFAULT_CONFIGURATION_MODE_TIMEOUT_MS 60000
#define DEFAULT_WATCHDOG_TIMEOUT_MS 1000 * 20    // 20 seconds
#define DEFAULT_OTA_TIMEOUT_MS 1000 * 60 * 10    // 10 minutes
#define DEFAULT_MQTT_MESSAGE_TIMEOUT_MS 1000 * 5 // 5 seconds

#define DEFAULT_SSID_MAX_LENGTH 33
#define DEFAULT_PASSWORD_MAX_LENGTH 65
#define DEFAULT_API_URL "http://blumy.cloud/api/v2/data"
#define DEFAULT_FIRMWARE_UPDATE_URL "http://firmware.blumy.cloud/firmware/firmware.bin"

#define DEFAULT_LED_BRIGHTNESS 128 // Default brightness for LEDs between 0 and 255

#define MAX_MOISTURE_MEASUREMENT 2500

#define DEFAULT_SSID_BLUMY "Blumy"

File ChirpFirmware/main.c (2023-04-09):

#include <inttypes.h>
#include <avr/io.h>
#include <util/delay.h>
#include <avr/interrupt.h>
#include <avr/wdt.h>
#include <avr/sleep.h>
#include <avr/eeprom.h>
#include "usiTwiSlave.h"

#define FIRMWARE_VERSION 0x21 // 2.1

//------------ peripherals ----------------

#define LED_K PB0
#define LED_A PB1
#define BUZZER PA7

void inline ledOn()
{
    DDRB |= _BV(LED_A) | _BV(LED_K); // forward bias the LED
    PORTB &= ~_BV(LED_K);            // flash it to discharge the PN junction capacitance
    PORTB |= _BV(LED_A);
}

void inline ledOff()
{
    DDRB &= ~(_BV(LED_A) | _BV(LED_K));  // make pins inputs
    PORTB &= ~(_BV(LED_A) | _BV(LED_K)); // disable pullups
}

void inline initBuzzer()
{
    TCCR0A = 0; // reset timer1 configuration
    TCCR0B = 0;

    TCCR0A |= _BV(COM0B1); // Clear OC0B on Compare Match when up-counting. Set OC0B on Compare Match when down-counting.
    TCCR0A |= _BV(WGM00);  // PWM, Phase Correct, 8-bit
    TCCR0B |= _BV(CS00);   // start timer
}

void inline static beep()
{
    initBuzzer();
    OCR0B = 48;
    _delay_ms(42);
    TCCR0B = 0; // stop timer
    PORTA &= ~_BV(BUZZER);
}

void static chirp(uint8_t times)
{
    PRR &= ~_BV(PRTIM0);
    while (times-- > 0)
    {
        beep();
        _delay_ms(40);
    }
    PRR |= _BV(PRTIM0);
}

static inline void playHappy()
{
    chirp(9);
    _delay_ms(350);
    chirp(1);
    _delay_ms(50);
    chirp(1);
}

static inline void playUnhappy()
{
    chirp(3);
}

//------------------- initialization/setup-------------------

static inline void inline setupGPIO()
{
    PORTA |= _BV(PA0); // nothing
    PORTA &= ~_BV(PA0);
    PORTA |= _BV(PA2); // nothing
    PORTA &= ~_BV(PA2);
    PORTA |= _BV(PA3); // nothing
    PORTA &= ~_BV(PA3);
    DDRA |= _BV(PA7); // nothing
    PORTA &= ~_BV(PA7);

    DDRB |= _BV(PB0); // nothing
    PORTB &= ~_BV(PB0);
    DDRB |= _BV(PB1); // nothing
    PORTB &= ~_BV(PB1);
    DDRB |= _BV(PB2); // sqare wave output
    PORTB &= ~_BV(PB2);
}

//--------------- sleep / wakeup routines --------------

void inline sleepWhileADC()
{
    set_sleep_mode(SLEEP_MODE_ADC);
    //    while(1) {
    sleep_mode();
    //    }
}

ISR(ADC_vect)
{
    // nothing, just wake up
}

// ------------------ capacitance measurement ------------------

static inline void startExcitationSignal()
{
    OCR0A = 0;
    TCCR0A = _BV(COM0A0) | // Toggle OC0A on Compare Match
             _BV(WGM01);   // reset timer to 0 on Compare Match
    TCNT0 = 254;
    TCCR0B = _BV(CS00);
}

void stopExcitationSignal() {
	TCCR0B = 0;
	TCCR0A = 0;
    PORTB &= ~_BV(PB2);
}

static inline void initADC()
{
    ADCSRA |= _BV(ADPS2); // adc clock speed = sysclk/16
    ADCSRA |= _BV(ADIE);
    ADCSRA |= _BV(ADEN);
}

static inline uint16_t getADC1()
{
    ADMUX = _BV(MUX0); // select ADC1 as input

    ADCSRA |= _BV(ADSC); // start conversion

    sleepWhileADC();

    uint16_t result = ADCL;
    result |= ADCH << 8;

    return 1023 - result;
}

uint16_t getCapacitance() {    
    PRR &= ~_BV(PRTIM0);
	startExcitationSignal();

    getADC1();
    _delay_ms(1000); // stabilize delay
    uint16_t result = getADC1();
    
    stopExcitationSignal();
    PORTB &= ~_BV(PB2);
    PRR |= _BV(PRTIM0);

    return result;
}

// ------------------ temperature measurement ------------------

uint16_t getADC8()
{
    ADMUX = 0b10100010; // select ADC8 as input, internal 1.1V Vref

    ADCSRA |= _BV(ADSC); // start conversion

    sleepWhileADC();

    uint16_t result = ADCL;
    result |= ADCH << 8;

    return result;
}

static inline uint16_t getTemperature()
{
    getADC8(); // discard the first measurement
    return getADC8();
}

//--------------------- light measurement --------------------

volatile uint16_t light = 0;
volatile uint16_t lightCounter = 0;
volatile uint8_t lightCycleOver = 1;

static inline stopLightMeaseurement()
{
    GIMSK &= ~_BV(PCIE1);
    TCCR1B = 0;
    PCMSK1 &= ~_BV(PCINT8);
    TIMSK1 &= ~_BV(TOIE1);

    lightCycleOver = 1;
}

ISR(PCINT1_vect)
{
    GIMSK &= ~_BV(PCIE1); // disable pin change interrupts
    TCCR1B = 0;           // stop timer
    lightCounter = TCNT1;
    light = lightCounter;

    stopLightMeaseurement();
}

ISR(TIM1_OVF_vect)
{
    lightCounter = 65535;
    light = lightCounter;

    stopLightMeaseurement();
}

static inline uint16_t getLight()
{
    TIMSK1 |= _BV(TOIE1); // enable timer overflow interrupt

    DDRB |= _BV(LED_A) | _BV(LED_K); // forward bias the LED
    PORTB &= ~_BV(LED_K);            // flash it to discharge the PN junction capacitance
    PORTB |= _BV(LED_A);

    PORTB |= _BV(LED_K); // reverse bias LED to charge capacitance in it
    PORTB &= ~_BV(LED_A);

    DDRB &= ~_BV(LED_K);                 // make Cathode input
    PORTB &= ~(_BV(LED_A) | _BV(LED_K)); // disable pullups

    TCNT1 = 0;
    TCCR1A = 0;
    TCCR1B = _BV(CS11) | _BV(CS10); // start timer1 with prescaler clk/64

    PCMSK1 |= _BV(PCINT8); // enable pin change interrupt on LED_K
    GIMSK |= _BV(PCIE1);

    lightCycleOver = 0;
}

static inline uint8_t lightMeasurementInProgress()
{
    return !lightCycleOver;
}

// ----------------- sensor mode loop ---------------------

#define I2C_GET_CAPACITANCE 0x00
#define I2C_SET_ADDRESS 0x01
#define I2C_GET_ADDRESS 0x02
#define I2C_MEASURE_LIGHT 0x03
#define I2C_GET_LIGHT 0x04
#define I2C_GET_TEMPERATURE 0x05
#define I2C_RESET 0x06
#define I2C_GET_VERSION 0x07
#define I2C_CHIRP_HAPPY 0x08
#define I2C_CHIRP_UNHAPPY 0x09
#define I2C_LED_ON 0x0A
#define I2C_LED_OFF 0x0B

#define reset()            \
    wdt_enable(WDTO_15MS); \
    while (1)              \
    {                      \
    }

static inline void loopSensorMode()
{
    startExcitationSignal();
    uint16_t currCapacitance = 0;
    uint16_t temperature = 0;

    while (1)
    {
        if (usiTwiDataInReceiveBuffer())
        {
            uint8_t usiRx = usiTwiReceiveByte();

            if (I2C_GET_CAPACITANCE == usiRx)
            {
                currCapacitance = getCapacitance();
                usiTwiTransmitByte(currCapacitance >> 8);
                usiTwiTransmitByte(currCapacitance & 0x00FF);
            }
            else if (I2C_SET_ADDRESS == usiRx)
            {
                uint8_t newAddress = usiTwiReceiveByte();
                if (newAddress >= 0 && newAddress <= 127)
                {
                    eeprom_write_byte((uint8_t *)0x01, newAddress);
                }
            }
            else if (I2C_GET_ADDRESS == usiRx)
            {
                uint8_t newAddress = eeprom_read_byte((uint8_t *)0x01);
                usiTwiTransmitByte(newAddress);
            }
            else if (I2C_MEASURE_LIGHT == usiRx)
            {
                if (!lightMeasurementInProgress())
                {
                    getLight();
                }
            }
            else if (I2C_GET_LIGHT == usiRx)
            {
                GIMSK &= ~_BV(PCIE1); // disable pin change interrupts
                TCCR1B = 0;           // stop timer

                usiTwiTransmitByte(light >> 8);
                usiTwiTransmitByte(light & 0x00FF);

                GIMSK |= _BV(PCIE1);
                TCCR1B = _BV(CS11) | _BV(CS10); // start timer1 with prescaler clk/64
            }
            else if (I2C_GET_TEMPERATURE == usiRx)
            {
                temperature = getTemperature();
                usiTwiTransmitByte(temperature >> 8);
                usiTwiTransmitByte(temperature & 0x00FF);
            }
            else if (I2C_RESET == usiRx)
            {
                reset();
            }
            else if (I2C_GET_VERSION == usiRx)
            {
                usiTwiTransmitByte(FIRMWARE_VERSION);
            }
            else if (I2C_CHIRP_HAPPY == usiRx)
            {
                playHappy();
            }
            else if (I2C_CHIRP_UNHAPPY == usiRx)
            {
                playUnhappy();
            }
            else if (I2C_LED_ON == usiRx)
            {
                ledOn();
            }
            else if (I2C_LED_OFF == usiRx)
            {
                ledOff();
            }
        }
    }
}

//-----------------------------------------------------------------

#define I2C_ADDRESS_EEPROM_LOCATION (uint8_t *)0x01
#define I2C_ADDRESS_DEFAULT 4

int main(void)
{
    MCUSR = 0;
    wdt_disable();
    setupGPIO();
    initADC();

    uint8_t address = eeprom_read_byte(I2C_ADDRESS_EEPROM_LOCATION);
    if (address <= 0 || address >= 127) // if eeprom address is 127 or 0, use default address
    {
        address = I2C_ADDRESS_DEFAULT;
    }
    usiTwiSlaveInit(address);

    CLKPR = _BV(CLKPCE);
    CLKPR = _BV(CLKPS1); // clock speed = clk/4 = 2Mhz

    sei();

    loopSensorMode();
}

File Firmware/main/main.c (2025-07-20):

#include "freertos/FreeRTOS.h"
#include "freertos/task.h"
#include "esp_log.h"
#include "nvs_flash.h"
#include "esp_sleep.h"
#include "esp_timer.h"

#include "esp_http_client.h"
#include <sys/socket.h>
#include <netinet/in.h>
#include <string.h>

#include "peripherals/sensors.h"
#include "plantfi.h"
#include "configuration_mode_server.h"
#include "plantstore.h"
#include "defaults.h"
#include "update.h"
#include "plantnow.h"

void wait_until_boot_button_released()
{
    ESP_LOGI("BOOT", "Waiting for boot button to be released");
    while (sensors_isBootButtonPressed())
    {
        vTaskDelay(10 / portTICK_PERIOD_MS); // Reset watchdog
    }
    ESP_LOGI("BOOT", "Boot button released");
}

void start_deep_sleep()
{
    uint64_t sleepTime = DEFAULT_SENSOR_TIMEOUT_SLEEP_MS;
    plantstore_getSensorTimeoutSleepMs(&sleepTime);
    sleepTime *= 1000;
    ESP_LOGI("DeepSleep", "Going to sleep for %llu us", sleepTime);
    wait_until_boot_button_released(); // Having the button pressed during deep sleep can cause issues on wakeup
    esp_deep_sleep(sleepTime);
}

bool isStaConnectionFresh = true;
bool isStaConnectingFresh = true;
uint8_t ledBrightness = DEFAULT_LED_BRIGHTNESS;
void handleLedsForWifiEvents()
{
    bool staConnected = plantfi_is_sta_connected() && isStaConnectionFresh;
    bool staDisconnected = !plantfi_is_sta_connected() && !isStaConnectionFresh;
    bool staStartedConnecting = plantfi_is_sta_connecting() && isStaConnectingFresh;
    bool staStoppedConnecting = !plantfi_is_sta_connecting() && !isStaConnectingFresh;

    if (staStartedConnecting)
    {
        isStaConnectingFresh = false;
        sensors_blinkLedYellowAsync(0, 500, ledBrightness);
    }
    if (staStoppedConnecting)
    {
        isStaConnectingFresh = true;
        if (!plantfi_is_sta_connected())
        {
            sensors_setLedRedBrightness(ledBrightness);
        }
    }
    if (staConnected)
    {
        isStaConnectionFresh = false;
        sensors_setLedGreenBrightness(ledBrightness);
    }
    if (staDisconnected)
    {
        isStaConnectionFresh = true;
    }
}

void multi_configuration_mode()
{
    ESP_LOGI("MODE", "Starting multi configuration mode");
    sensors_setLedYellowBrightness(ledBrightness);
    plantnow_init(false); // Has to be called before configuring the sta or ap

    while (1)
    {
        if (sensors_isBootButtonPressed())
        {
            ESP_LOGI("MODE", "Boot button pressed, going to sleep");
            break;
        }
        if (plantnow_hasExchangedBlumy())
        {
            ESP_LOGI("MODE", "Blumy credentials exchanged, going to sensor mode");
            break;
        }
        vTaskDelay(10 / portTICK_PERIOD_MS); // Reset watchdog
    }
}

void single_configuration_mode(bool isConfigured)
{
    ESP_LOGI("MODE", "Starting single configuration mode%s", isConfigured ? " (sensor is configured)" : " (no config)");
    uint64_t start_time = esp_timer_get_time();
    uint64_t current_time = start_time;
    int32_t timeoutMs = DEFAULT_CONFIGURATION_MODE_TIMEOUT_MS;
    plantstore_getConfigurationModeTimeoutMs(&timeoutMs);

    plantnow_init(true); // Has to be called before configuring the sta or ap

    plantfi_setEnableNatAndDnsOnConnect(true);
    plantfi_configureAp(DEFAULT_SSID_BLUMY, "", 4);
    plantfi_configureStaFromPlantstore();

    ESP_LOGI("MODE", "Starting webserver");
    httpd_handle_t webserver = start_webserver();
    sensors_setLedRedBrightness(0);
    sensors_blinkLedGreenAsync(0, 500, ledBrightness);

    while (1)
    {
        if (isConfigured && !plantfi_is_user_connected_to_ap())
        {
            current_time = esp_timer_get_time();
            if (current_time - start_time > timeoutMs * 1000)
            {
                ESP_LOGI("MODE", "Timeout reached, going to sleep");
                break;
            }
        }
        else if (plantfi_is_user_connected_to_ap())
        {
            start_time = esp_timer_get_time(); // Reset timeout if user is connected
        }
        if (sensors_isBootButtonPressed())
        {
            ESP_LOGI("MODE", "Boot button pressed, going to sleep");
            break;
        }
        handleLedsForWifiEvents();
        vTaskDelay(10 / portTICK_PERIOD_MS); // Reset watchdog
    }
    stop_webserver(webserver);
}

void configuration_mode(bool isConfigured)
{
    ESP_LOGI("MODE", "Starting configuration mode%s", isConfigured ? " (sensor is configured)" : " (no config)");
    sensors_initSensors();
    plantstore_getLedBrightness(&ledBrightness);
    sensors_setLedRedBrightness(ledBrightness);
    sensors_playStartupSound();

    bool foundBlumyNetwork = plantfi_found_blumy_network();
    if (foundBlumyNetwork)
    {
        multi_configuration_mode();
    }
    else
    {
        single_configuration_mode(isConfigured);
    }

    sensors_playShutdownSound();
    sensors_setLedGreenBrightness(0);
    sensors_blinkLedRed(3, 100, ledBrightness);
    start_deep_sleep();
}

void watchdog_callback(void *arg)
{
    ESP_LOGE("Watchdog", "Watchdog timeout reached, going to sleep");
    start_deep_sleep();
}

esp_timer_handle_t init_watchdog(uint64_t timeoutMs)
{
    esp_timer_create_args_t watchdog_args = {
        .callback = &watchdog_callback,
        .name = "watchdog",
    };
    esp_timer_handle_t watchdog_timer;
    ESP_ERROR_CHECK(esp_timer_create(&watchdog_args, &watchdog_timer));
    uint64_t watchdog_timeout = timeoutMs;
    plantstore_getWatchdogTimeoutMs(&watchdog_timeout);

    ESP_LOGI("Watchdog", "Starting watchdog with timeout %llu ms", watchdog_timeout);
    ESP_ERROR_CHECK(esp_timer_start_once(watchdog_timer, watchdog_timeout * 1000));

    return watchdog_timer;
}

void sensor_mode()
{
    ESP_LOGI("MODE", "Starting sensor mode");
    esp_timer_handle_t watchdog_timer = init_watchdog(DEFAULT_WATCHDOG_TIMEOUT_MS);
    plantfi_configureStaFromPlantstore();
    sensors_initSensors();
    sensors_full_data_t sensors_data;
    sensors_full_read(&sensors_data);
    EventBits_t bits;
    ESP_ERROR_CHECK(plantfi_waitForStaConnection(&bits));
    int statusCode = 0;
    if (bits & PLANTFI_CONNECTED_BIT)
    {
        int8_t rssi = plantfi_getRssi();
        statusCode = plantfi_send_sensor_data_blumy(&sensors_data, rssi);
        plantfi_send_sensor_data_http(&sensors_data, rssi);
        plantfi_send_sensor_data_mqtt(&sensors_data, rssi);
    }
    else
    {
        ESP_LOGE("WIFI", "Failed to connect to wifi");
    }
    sensors_deinitSensors(); // optional
    if (statusCode == 426)
    {
        ESP_ERROR_CHECK(esp_timer_stop(watchdog_timer));
        watchdog_timer = init_watchdog(DEFAULT_OTA_TIMEOUT_MS);
        update_updateFirmware(NULL);
        // wait indefinitely for the update to complete
        while (1)
        {
            vTaskDelay(1000 / portTICK_PERIOD_MS);
        }
    }
    ESP_ERROR_CHECK(esp_timer_stop(watchdog_timer));
    start_deep_sleep();
}
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

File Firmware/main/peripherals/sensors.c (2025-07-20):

#include "peripherals/sensors.h"

#include "freertos/FreeRTOS.h"
#include "freertos/task.h"
#include "driver/gpio.h"
#include "driver/ledc.h"
#include "esp_timer.h"
#include "driver/i2c.h"
#include "aht20.h"
#include "esp_log.h"

#include "peripherals/adc.h"
#include "peripherals/config.h"

#include "defaults.h"

const unsigned long maxStabilizationTime = 500;
const int stabilizationDifference = 5;

bool isSensorsInit = false;

unsigned long millis()
{
    return esp_timer_get_time() / 1000;
}

bool ledc_initialized[LEDC_CHANNEL_MAX] = {false};

/**
 * @param duty_cycle Duty cycle in percentage (0.0 to 1.0)
 */
void analogWrite(int gpio, int frequency, float duty_cycle, ledc_channel_t channel)
{
    if (duty_cycle <= 0)
    {
        if (ledc_initialized[channel])
        {
            ledc_stop(LEDC_LOW_SPEED_MODE, channel, 0);
        }
        return;
    }
    ledc_timer_bit_t duty_resolution = LEDC_TIMER_13_BIT;
    if (frequency < 1000)
    {
        duty_resolution = LEDC_TIMER_10_BIT;
    }
    else if (frequency < 10000)
    {
        duty_resolution = LEDC_TIMER_9_BIT;
    }
    else if (frequency < 100000)
    {
        duty_resolution = LEDC_TIMER_7_BIT;
    }
    else if (frequency < 1000000)
    {
        duty_resolution = LEDC_TIMER_5_BIT;
    }
    else
    {
        duty_resolution = LEDC_TIMER_3_BIT;
    }
    ledc_timer_config_t ledc_timer = {
        .duty_resolution = duty_resolution,
        .freq_hz = frequency,
        .speed_mode = LEDC_LOW_SPEED_MODE,
        .timer_num = LEDC_TIMER_0};
    ESP_ERROR_CHECK(ledc_timer_config(&ledc_timer));

    uint32_t duty = (1 << duty_resolution) * duty_cycle;
    if (!ledc_initialized[channel])
    {
        ledc_initialized[channel] = true;
        ledc_channel_config_t ledc_channel = {
            .gpio_num = gpio,
            .speed_mode = LEDC_LOW_SPEED_MODE,
            .channel = channel,
            .intr_type = LEDC_INTR_DISABLE,
            .timer_sel = LEDC_TIMER_0,
            .duty = duty,
            .hpoint = 0};
        ESP_ERROR_CHECK(ledc_channel_config(&ledc_channel));
    }
    else
    {
        ledc_set_duty(LEDC_LOW_SPEED_MODE, channel, duty);
        ledc_update_duty(LEDC_LOW_SPEED_MODE, channel);
    }
    vTaskDelay(10 / portTICK_PERIOD_MS); // Calling ledc back to back hangs up the esp
}

TimerHandle_t toneTimer;
void buzzerOffCallback(TimerHandle_t xTimer)
{
    analogWrite(blumy_config.BUZZER, 0, 0, blumy_config.BUZZER_CHANNEL);
}
void sensors_playToneAsync(int frequency, int duration_ms)
{
    analogWrite(blumy_config.BUZZER, frequency, 0.5, blumy_config.BUZZER_CHANNEL);

    if (toneTimer == NULL)
    {
        toneTimer = xTimerCreate("ToneTimer", pdMS_TO_TICKS(duration_ms), pdFALSE, NULL, buzzerOffCallback);
    }
    else
    {
        xTimerChangePeriod(toneTimer, pdMS_TO_TICKS(duration_ms), 0);
    }
    xTimerStart(toneTimer, 0);
}
void sensors_playToneSync(int frequency, int duration_ms)
{
    analogWrite(blumy_config.BUZZER, frequency, 0.5, blumy_config.BUZZER_CHANNEL);
    vTaskDelay(duration_ms / portTICK_PERIOD_MS);
    analogWrite(blumy_config.BUZZER, 0, 0, blumy_config.BUZZER_CHANNEL);
}

void setLedBrightness(int led_pin, uint8_t brightness)
{
    float duty_cycle = (brightness / 255.0f) * (brightness / 255.0f); // Square the brightness for a more linear perception
    if (led_pin == blumy_config.LED_RED)
    {
        analogWrite(blumy_config.LED_RED, 5000, duty_cycle, blumy_config.LED_RED_CHANNEL);
    }
    else if (led_pin == blumy_config.LED_GREEN)
    {
        analogWrite(blumy_config.LED_GREEN, 5000, duty_cycle, blumy_config.LED_GREEN_CHANNEL);
    }
    else
    {
        ESP_LOGE("SENSORS", "Invalid LED pin: %d", led_pin);
    }
}

typedef struct
{
    bool led_red;
    bool led_green;
    int times;
    int duration_ms;
    uint8_t brightness;
} led_blink_params_t;
led_blink_params_t led_blink_params = {
    .led_red = false,
    .led_green = false,
    .times = 0,
    .duration_ms = 0,
    .brightness = 0.0f};
TaskHandle_t led_blink_task_handle = NULL;

void stop_led_blink_task()
{
    if (led_blink_task_handle != NULL)
    {
        vTaskDelete(led_blink_task_handle);
        led_blink_task_handle = NULL; // Reset the handle
        led_blink_params.led_red = false;
        led_blink_params.led_green = false;
        led_blink_params.times = 0;
        led_blink_params.duration_ms = 0;
    }
}

void sensors_setLedRedBrightness(uint8_t brightness)
{
    stop_led_blink_task();
    setLedBrightness(blumy_config.LED_GREEN, 0.0);
    setLedBrightness(blumy_config.LED_RED, brightness);
}

void sensors_setLedGreenBrightness(uint8_t brightness)
{
    stop_led_blink_task();
    setLedBrightness(blumy_config.LED_RED, 0.0);
    setLedBrightness(blumy_config.LED_GREEN, brightness);
}

void sensors_setLedYellowBrightness(uint8_t brightness)
{
    stop_led_blink_task();
    setLedBrightness(blumy_config.LED_RED, brightness);
    setLedBrightness(blumy_config.LED_GREEN, brightness);
}

void blinkLed(bool led_red, bool led_green, int times, int duration_ms, uint8_t brightness)
{
    int count = 0;
    while (times <= 0 || count < times)
    {
        if (led_red)
        {
            setLedBrightness(blumy_config.LED_RED, brightness);
        }
        if (led_green)
        {
            setLedBrightness(blumy_config.LED_GREEN, brightness);
        }
        vTaskDelay(duration_ms / portTICK_PERIOD_MS);

        if (led_red)
        {
            setLedBrightness(blumy_config.LED_RED, 0.0);
        }
        if (led_green)
        {
            setLedBrightness(blumy_config.LED_GREEN, 0.0);
        }
        vTaskDelay(duration_ms / portTICK_PERIOD_MS);

        if (times > 0)
        {
            count++;
        }
    }
}

void sensors_blinkLedRed(int times, int duration_ms, uint8_t brightness)
{
    setLedBrightness(blumy_config.LED_GREEN, 0.0);
    blinkLed(true, false, times, duration_ms, brightness);
}

void sensors_blinkLedGreen(int times, int duration_ms, uint8_t brightness)
{
    setLedBrightness(blumy_config.LED_RED, 0.0);
    blinkLed(false, true, times, duration_ms, brightness);
}

void sensors_blinkLedYellow(int times, int duration_ms, uint8_t brightness)
{
    blinkLed(true, true, times, duration_ms, brightness);
}

void led_blink_task(void *params)
{
    led_blink_params_t *blink_params = (led_blink_params_t *)params;

    blinkLed(blink_params->led_red, blink_params->led_green, blink_params->times, blink_params->duration_ms, blink_params->brightness);

    vTaskDelete(NULL); // Delete this task when done
}

void sensors_blinkLedRedAsync(int times, int duration_ms, uint8_t brightness)
{
    stop_led_blink_task();
    led_blink_params.led_red = true;
    led_blink_params.led_green = false;
    led_blink_params.times = times;
    led_blink_params.duration_ms = duration_ms;
    led_blink_params.brightness = brightness;
    xTaskCreate(led_blink_task, "LED_Blink_Task", 2048, &led_blink_params, tskIDLE_PRIORITY + 1, &led_blink_task_handle);
}
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

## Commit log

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2023-04-09 fixed frontend landing in wrong folder
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2023-05-08 Add board schematics KiCad
    [BOM-ESPlant-Board.csv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]
2023-05-09 Add reset circuit to schematics
    [ESPlant-Board.kicad_pcb, ESPlant-Board.kicad_sch]
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2023-05-10 Add JLCPCB part ids
    [BOM-ESPlant-Board.csv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]
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2023-05-12 Add version 1.0 lable
    [ESPlant-Board.kicad_pcb, positions.csv]
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2023-05-12 Fix ESP-Position bug
    [ESPlant-Board.kicad_sch, positions.csv]
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2023-05-12 Replace layout to use battery pack
    [ESPlant-Board.kicad_pcb, ESPlant-Board.kicad_sch, bom.csv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]
2023-05-12 Add meta info to schematic
    [ESPlant-Board.kicad_sch]
2023-05-12 Replace PWR_FLAG with power output
    [ESPlant-Board.kicad_sch]
2023-05-12 Add backups and production files to gitignore
    [ESPlant-Board.kicad_sch, bom.csv, designators.csv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]
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2023-05-12 Add preview for v1.2
    [ESPlant-Board.kicad_pcb, ESPlant-Board.kicad_sch, bom.csv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]
2023-05-12 Change default project v1.2 to v1.1
    [ESPlant-Board.kicad_pcb]
2023-05-13 Add Ground plane to v1.1
    [ESPlant-Board.kicad_pcb, ESPlant-Board.kicad_sch, positions.csv]
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2023-05-26 firmware: added reset modes
    [ConfigurationMode.h]
2023-05-26 firmware: added configuration mode led
    [ConfigurationMode.h]
2023-05-26 firmware: added webserver for configuration mode
    [ConfigurationMode.h]
2023-05-26 firmware: added auto wifi scan
    [ConfigurationMode.h]
2023-05-26 firmware: added wifi connection
    [ConfigurationMode.h]
2023-05-26 firmware: fixed reset button
2023-05-26 firmware: fixed reset not being async
    [ConfigurationMode.h]
2023-05-26 firmware: added double reset going to sensor mode
2023-05-26 firmware: added ota mode template
    [ConfigurationMode.h]
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2023-05-30 firmware: added captive portal
    [ConfigurationMode.h]
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2023-05-31 firmware: cleaned up code
    [ConfigurationMode.h]
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2023-06-03 firmware: added partitions table
    [partition.csv]
2023-06-03 firmware: fixed configuration website
    [ConfigurationMode.h]
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2023-06-05 firmware: removed partitions csv
    [partition.csv]
2023-06-12 firmware: Dirty filesystem too big fix
    [ConfigurationMode.h]
2023-06-12 firmware, frontend: changed upload endpoints
    [ConfigurationMode.h]
2023-06-12 frontend: added progress bar
    [ConfigurationMode.h]
2023-06-14 frontend: migrated to lit
    [ConfigurationMode.h]
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2023-06-15 firmware: added plant name
    [ConfigurationMode.h]
2023-06-15 frontend: added sensor reset
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2023-06-15 firmware, frontend: added sleep timeout setting
    [ConfigurationMode.h]
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2023-06-18 board: working on v2
    [ESPlant-Board.kicad_sch]
2023-06-19 Added light sensor to schematic
    [ESPlant-Board.kicad_sch]
2023-06-20 frontend, firmware: added homepage with value preview
    [ConfigurationMode.h]
2023-06-26 dashboard: sort query data by key (#7)
    * Added query data sorting
    * dashboard: fixed some comparison issues
    * dashboard: fixed sorting by capacitance
    * Added table sorting ui
    * dashboard: Added next watering as default sorting
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2023-07-04 board: Add buzzer
    [ESPlant-Board.kicad_pcb, ESPlant-Board.kicad_sch]
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2023-07-09 Fix esp schematic pins
    [ESPlant-Board.kicad_sch]
2023-07-09 Add silkscreen to important components
    [ESPlant-Board.kicad_pcb, ESPlant-Board.kicad_sch, positions.csv]
2023-07-15 api: Fix error creating new sensor
2023-07-15 Update pcb for v2.0
    [ESPlant-Board.kicad_pcb, ESPlant-Board.kicad_sch, bom.csv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]
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2023-07-16 dashboard: Redesign sensor page
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2023-07-26 board: remove redundant parts
    [ESPlant-Board.kicad_pcb, ESPlant-Board.kicad_sch]
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2023-07-26 board: fix
2023-07-29 Board: finalize small version, Case: create file
    [ESPlant-Board.kicad_pcb, ESPlant-Board.kicad_sch, ESPlant-Case.FCStd]
2023-07-30 Case: Finish first draft
    [ESPlant-Board.kicad_pcb, ESPlant-Case.FCStd]
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2023-08-06 board, case: more work
    [ESPlant-Board.kicad_pcb, ESPlant-Board.kicad_sch, bom.csv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]
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2023-08-27 Board: changed to esp32-c6-mini-1-n4
    [ESPlant-Board.kicad_pcb, ESPlant-Board.kicad_sch]
2023-08-27 Board: Add panel for esp32-c6
    [ESPlant-Board.kicad_pcb, ESPlant-Board.kicad_sch, bom.csv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]
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2023-09-01 Case: Add v2 case with improved folder structure
    [ESPlant-Board.kicad_pcb, ESPlant-Board.kicad_sch, ESPlant-Case-v2.FCStd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]
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2023-09-02 Make case print ready
    [ESPlant-Case-v2-CaseBottom.obj, ESPlant-Case-v2-CaseBottom.step, ESPlant-Case-v2-CaseOver.obj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]
2023-09-02 Finish v2.0 for prototyping
    [ESPlant-Board.kicad_pcb, ESPlant-Board.kicad_sch, bom.csv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]
2023-09-03 Board: Can now differentiate between usb or battery connected
    [ESPlant-Board.kicad_pcb, ESPlant-Board.kicad_sch]
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2023-09-14 Board: Add kicad-libraries as submodule
    [ESPlant-Board.kicad_pcb]
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2023-09-24 Board: Fix library paths
    [ESPlant-Board.kicad_pcb, ESPlant-Board.kicad_sch]
2023-09-24 Case: Fix battery_spring sizes
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2023-09-25 Board replace wrl with step files
    [ESPlant-Board.kicad_pcb]
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2023-10-02 Case: Fix part rotation
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2023-10-07 Fix board converter paths
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2023-11-23 Case: add pcb board tolerance
2023-11-23 Case: add TODO for pcb tolerance generation
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2023-11-28 Case: Fix extrude_part_faces arguments order
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2023-11-28 Case: Revert changes to part settings
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2023-11-30 Case: Add snap joint to compartment door fitting arm
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2023-12-03 Case: Compartment door Vector fix
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2023-12-03 Case: Fix Snapjoint
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2023-12-07 Case: Merge Settings and Tolerance classes
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2023-12-07 Case: Fix component names and positions
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2023-12-11 Board: Reset KiCad Version to not-nightly
    [ESPlant-Board.kicad_pcb, ESPlant-Board.kicad_sch]
2023-12-12 Add new parameters for PCB tolerance and fixation hole diameter
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2023-12-12 Case: Insert dummy data (does not fix the problem)
2023-12-13 Case: Fix _bool_op bug
2023-12-13 Case: Add logging and fix make_offset_shape for pcb
2023-12-13 Case: Fix _bool_op workarround by using inline imports
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2023-12-13 Case: Replace Jinja extension with betterjinja
2023-12-13 Case: Fix casemaker showing attributes it does not have
2023-12-13 Board: Add MICRO-USB step
    [ESPlant-Board.kicad_pcb]
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2023-12-15 Casemaker: Fix mounting hole on bottom side
2023-12-15 Board: Make mounting holes bigger
    [ESPlant-Board.kicad_pcb]
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2023-12-17 Casemaker: Add option to create pcb_slot with components silhouette and or tolerances
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2023-12-17 Casemaker: Add missing documentation for mounting holes
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2023-12-17 Board: Increase sensor padding to tip
    [ESPlant-Board.kicad_pcb]
2023-12-18 Casemaker: Add Sexp parser to find and replace missing 3d models in kicad_pcb
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2023-12-21 Fix error when loading board that does not exist yet
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2023-12-22 Fix selection of default PCB part
2023-12-24 Casemaker: Update ESPlant-Battery holder tolerances
2023-12-24 Board: Replace Micro USB with USB type c
    [ESPlant-Board.kicad_pcb, ESPlant-Board.kicad_sch]
2023-12-24 Board: Make board smaller
    [ESPlant-Board.kicad_pcb, ESPlant-Board.kicad_sch]
2023-12-24 Board: Add version number 2.1
    [ESPlant-Board.kicad_pcb]
2023-12-28 Board: Change from aht21 to aht21, fix kikit, produce board
    [ESPlant-Board.kicad_pcb, ESPlant-Board.kicad_sch, bom.csv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]
2023-12-31 Fix wrong sensor names
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2024-01-05 Board: Update panel production data
    [bom.csv, designators.csv, positions.csv]
2024-01-05 Casemaker: Add brackets to default name replace map
2024-01-05 Fix skewed camera in board renderer
2024-01-05 Fix case generation
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2024-02-11 Board: Make ESPlant-Board 4 layer (wip)
    [ESPlant-Board.kicad_pcb, ESPlant-Board.kicad_sch]
2024-02-17 Board: Change from 2-layer to 4-layer board
    [ESPlant-Board.kicad_pcb, Moisture-sensor-test-pcbs.kicad_pcb, Moisture-sensor-test-pcbs.kicad_sch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]
2024-02-17 Panel: Add panelization script
    [ESPlant-Board.kicad_pcb, ESPlant-Board.kicad_sch, bom.csv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]
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2024-03-01 Board: New power supply chip
    [ESPlant-Board.kicad_pcb, ESPlant-Board.kicad_sch, bom.csv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]
2024-03-01 Panel: Add production data
    [bom.csv, designators.csv, positions.csv]
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2024-03-02 Panel: Update production files
    [ESPlant-Board.kicad_pcb, bom.csv, designators.csv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]
2024-03-02 Board: Add debouncing caps to buttons
    [ESPlant-Board.kicad_pcb, ESPlant-Board.kicad_sch, bom.csv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]
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2024-03-02 Panel: Add voltage divider for checking usb connection
    [ESPlant-Board.kicad_pcb, ESPlant-Board.kicad_sch, bom.csv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]
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2024-03-02 Case: Fix battery spring size
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2024-03-16 Fix incorrect capacitor size
    [ESPlant-Board.kicad_pcb, ESPlant-Board.kicad_sch, bom.csv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]
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2024-03-26 ESPlant-Firmware: Fix light sensor return value
    [main.c]
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2024-03-27 Board: Replace Light Sensor Select with ground
    [ESPlant-Board.kicad_sch]
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2024-03-28 Firmware: Fix littlefs
    [partitions.csv]
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2024-03-31 Firmware: Fix bugs
    [configuration_mode_server.h]
2024-03-31 Firmware: Fix deepsleep timeout
    [main.c, plantstore.h]
2024-04-01 Firmware: Add startup and shutdown sounds, fix wifi
    [main.c, plantstore.h, sensors.c]
2024-04-01 Firmware: Add reset handler
    [main.c]
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2024-04-01 Firmware: Replace 8266 firmware with c6 firmware
    [ConfigurationMode.h, configuration_mode_server.h, partitions.csv]
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2024-04-03 Fix sensor renaming
2024-04-04 Firmware fix sleep timeout logs
    [main.c]
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2024-04-05 Firmware: Fix http client cleanup too early
    [main.c]
2024-04-06 Casemaker: Fix battery spring dimensions
2024-04-06 Firmware: Fix config button not enabled
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2024-08-04 Board: Update to V8, add battery springs 3d models
    [ESPlant-Board.kicad_pcb, ESPlant-Board.kicad_sch]
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2024-09-03 Fix mistake
    [partitions.csv]
2024-09-03 Add qol to configuration mode, fix ota update percentage
    [main.c, plantstore.h]
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2024-09-05 Add https server to prevent mixed protocol errors
    [configuration_mode_server.h]
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2024-09-05 Remove https server because I don't want to have to manage ssl certificates
    [configuration_mode_server.h]
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2024-09-11 Fix sensor ota update percentage
    [configuration_mode_server.h]
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2024-10-02 Fix sensor link and update delete message
2025-06-23 Update and fix Board and Panel
    [Board.kicad_pcb, Board.kicad_sch, bom.csv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]
2025-06-25 Update Blumy Firmware to use leds and fix configuration bugs
    [configuration_mode_server.h]
2025-06-25 Add firmware version and fix led brightness handler
2025-06-25 Add automatic updates and fix factory reset not resetting wifi
    [defaults.h, main.c]
2025-06-25 Fix weird ledc bug
    [main.c, sensors.c]
2025-06-26 Add missing tabs to blumy panel
    [Board.kicad_pcb, Board.kicad_sch, panel.kicad_pcb]
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2025-06-27 Replace flower symbol
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2025-07-12 Fix home assistant sensor values
    [defaults.h, sensors.c]
2025-07-12 Fix voltage configurations, remove isUsbConnected property
    [config.h, sensors.c]
2025-07-12 Fix leds being on during sensor mode bug
    [sensors.c]
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2025-07-17 Remove boot capacitor from blumy and flip usb bat text
    [Board.kicad_pcb, Board.kicad_sch]
2025-07-19 Fix esp crashes with broken aht sensor
    [sensors.c]
2025-07-20 Fix back to home page button
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2025-07-20 Fix configuration and ledc warnings
    [sensors.c]
2025-07-23 Add option to add multiple sensors via share link and fix double submission bug
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2025-07-27 Fix sensor capacity history card size
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2025-07-29 Implement lazy loading of sensor images with separate database table (#32)
    * Implement lazy loading of sensor images with separate table
    * Replace image url with typesafe clientApi
    ---------
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2025-07-31 Fix not being able to change sensor settings
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2025-11-16 Fix capacity graph not showing sometimes
2025-11-16 Fix unsubscribing unsubscribes from all sensors
